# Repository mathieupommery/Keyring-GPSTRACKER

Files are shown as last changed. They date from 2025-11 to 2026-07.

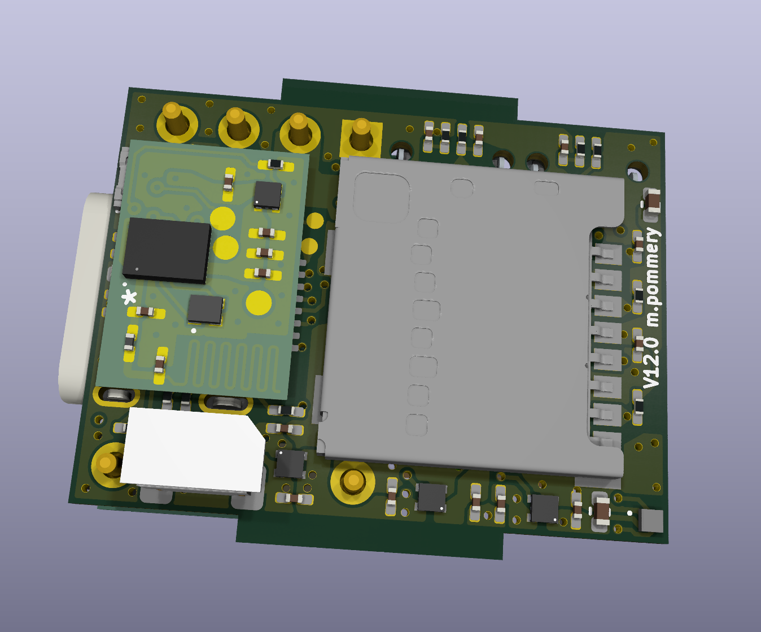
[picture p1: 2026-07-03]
Docs/backv12withda14531.png

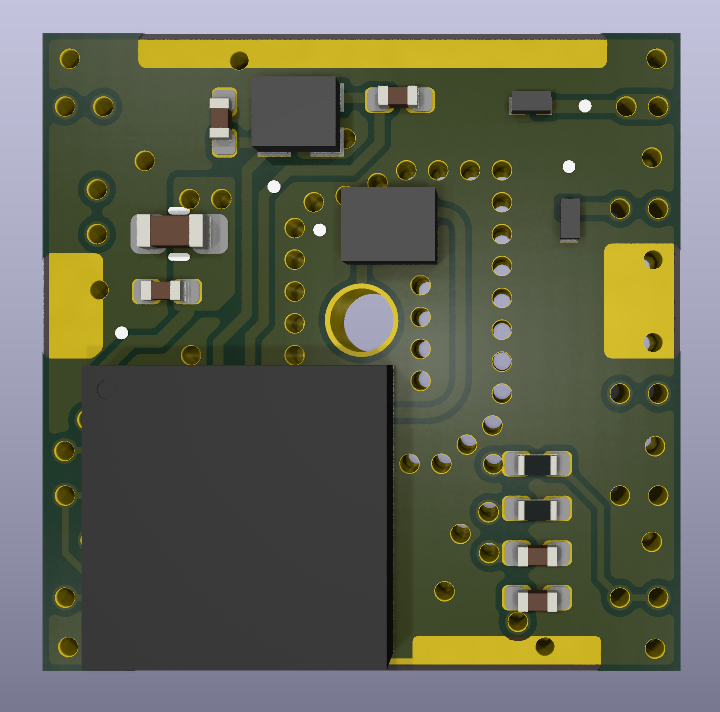
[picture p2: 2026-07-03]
Docs/gpstop.png

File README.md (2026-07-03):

# Keyring-GPSTRACKER (v12.0)

<p align="center">
  <video src="https://github.com/user-attachments/assets/1a3d3f26-0a68-42e8-81eb-b6b98553143f" width="600" controls autoplay loop muted></video>
</p>

An ultra-compact, highly integrated modular GPS logger built around the STM32G0B1KE and a custom u-blox MIA-M10Q implementation. This project is designed as a fully functional, wearable GNSS tracker featuring worldwide offline geographical awareness, high-frequency SD card logging, Bluetooth connectivity, extreme power management (2µA shutdown draw), and modular waterproof enclosures.

## Key Features

* **Configurable High-Speed Logging:** Records tracks directly to the internal MicroSD card in `.GPX` or `.CSV` format. The logging frequency is adjustable, supporting real-time capture from **1Hz up to 10Hz**.
* **Worldwide Offline Awareness & Navigation:** Anywhere in the world, the device can instantly identify the closest city (name, direction, population) or the nearest mountain peak. It provides precise directional pointers by fusing data from the GPS, the MMC5603 compass, and the ICM-42688-P IMU.
* **Topological Barometer Calibration:** Future firmware implementation of an offline map of topological elevation points stored on the SD card, allowing ultra-precise, automatic recalibration of the barometer altitude.
* **BLE Smartphone Connectivity:** An external **DA14531 Bluetooth Low Energy (BLE)** module will handle seamless, low-power synchronization and configuration with a smartphone app.
* **Plug & Play USB:** Acts as a USB Mass Storage Class (MSC) over USB-C. Simply plug the tracker into a computer to access the MicroSD card and retrieve your tracks without removing the card.
* **Extreme Low Power:** Fully active power draw is around ~30mA. In shutdown mode, with only 1 LDO running for the STM32, the system draws just **2µA**.

---

## Modular Hardware Ecosystem (4 Custom PCBs)

The project relies on an ecosystem of four custom PCBs (two 6-layer boards and two 2-layer boards) connected via ultra-compact 5-pin board-to-board connectors.

### 1. Mainboard (6-Layer)
The core of the tracker, engineered to maximize available I/O ports while maintaining a tiny footprint.
* **MCU:** STM32G0B1KE (chosen for native USB FS 2.0, ultra-low power shutdown modes, and only 1 VDD pin).
* **Internal Sensors:** MMC5603 (compass), ICM-42688-P (IMU), and DPS368 (barometer).
* **Storage & Connectivity:** MicroSD card slot operating in SPI mode + external DA14531 BLE module support.
* **Power & Charging:** LTC4065 LiPo battery charger with USB-C connector.

<p align="center">
  v12side
  v12top
</p>

#### BLE Expansion Module (DA14531)
To keep the mainboard ultra-compact while allowing wireless smartphone communication, wireless connectivity is offloaded to a dedicated mini extension PCB. Connected directly to the back of the mainboard via a board-to-board connector, this add-on integrates the ultra-low-power **Renesas DA14531 CodeLess BLE module**.

<p align="center">
  Mainboard Back - Without BLE Module
  backv12withda14531

</p>

### 2. Custom GNSS Receiver Board (6-Layer)
A custom BGA adaptation of the u-blox **MIA-M10Q** receiver with a dedicated SAW filter and a top-mounted ceramic patch antenna. Designed as a footprint clone of the PA1010D, but utilizing a far superior engine capable of 10Hz updates across all constellations simultaneously.

gpstop
gpsbottom

### 3. Display & Waterproof Extension Panel (Breakaway 2-Layer PCB)

To optimize manufacturing, all auxiliary modules are designed as a single **snap-away (breakaway) panelized 2-layer PCB** so they can be produced together in one manufacturing run. Once snapped apart, the panel yields three distinct functional boards:

* **0.42" OLED Carrier Board:** Adapts a 0.42-inch SSD1306 OLED screen to the custom 5/6-pin board-to-board (B2B) connector format. It also breaks out the I2C bus to an external JST SM05B connector and includes an external GPIO breakout for a hardware button.
* **0.49" OLED Carrier Board:** Identical architecture to the 0.42" version (B2B adaptation, JST SM05B I2C breakout, button GPIO), but specifically dimensioned to mount a slightly larger 0.49-inch SSD1306 OLED screen.
* **Waterproof Dive Extension Board:** Designed specifically to mount inside the waterproof enclosure for deep-water excursions. It adds a **TE Connectivity 30-bar external pressure sensor** (effectively turning the tracker into a compact dive computer) and a magnetic **Hall-effect switch** for contactless power/stop-mode toggling through the solid sealed case.

<p align="center">
  auxpcbside2
  auxpcbside1
</p>

## Smart Power Architecture

Power is cleanly isolated and distributed via 3 independent ultra-low IQ LDOs, controlled by the MCU:
* **LDO 1 (Always-on / MCU baseline):** Powers the STM32 directly. Responsible for the 2µA deep shutdown consumption.
* **LDO 2 (Switched):** Dedicated exclusively to the GNSS module.
* **LDO 3 (Switched):** Powers the SSD1306 display, the MicroSD card, external sensors (including the BLE module), and internal sensors.

---

## Enclosure System: Standard vs. Waterproof (Dive Mode)

The tracker features a modular, tool-free swap enclosure system depending on your activity:

### 1. Standard Compact Case
The daily-use enclosure. It is ultra-compact, non-waterproof, and provides direct access to the OLED display, physical buttons, MicroSD card slot, and USB-C port for charging and mass-storage data transfer.

balise

### 2. Waterproof Dive Case
Similar to a GoPro housing, this heavy-duty case is designed for underwater excursions down to several hundred meters. 
* **How it works:** You remove the mainboard from the standard case, connect it to the **Waterproof Extension Board** (with the 30-bar sensor and Hall switch already mounted inside the dive case), turn it on, and seal the enclosure.
* **Note:** While in this temporary dive case, USB charging and physical MicroSD card access are blocked to ensure 100% water tightness. Power state is managed entirely through the external magnetic Hall sensor.

watercase1

---

## Open Source

This project is fully open source! Feel free to explore the schematics, layouts, and firmware. If you find this project interesting or build your own, **please consider leaving a ⭐ on the repository!**

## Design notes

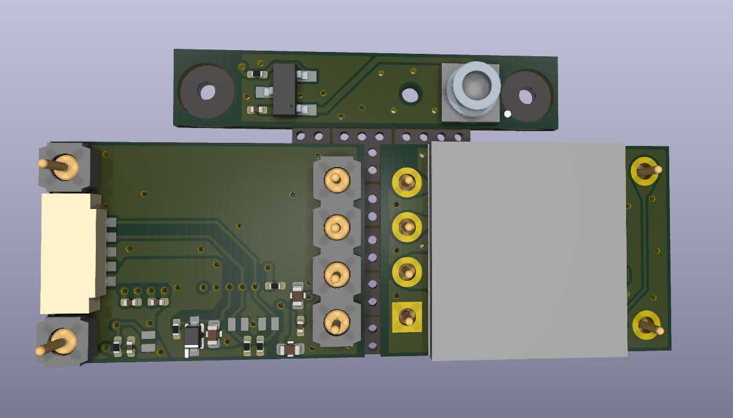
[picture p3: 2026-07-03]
Docs/auxpcbside1.png

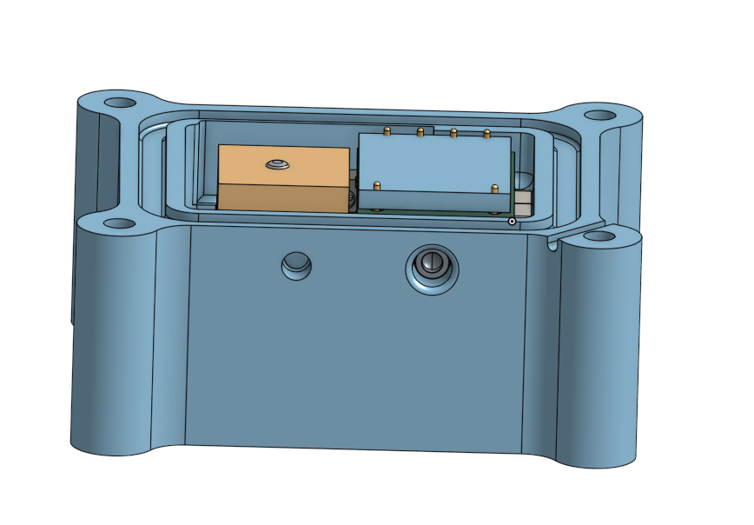
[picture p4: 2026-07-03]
Docs/watercase2.png

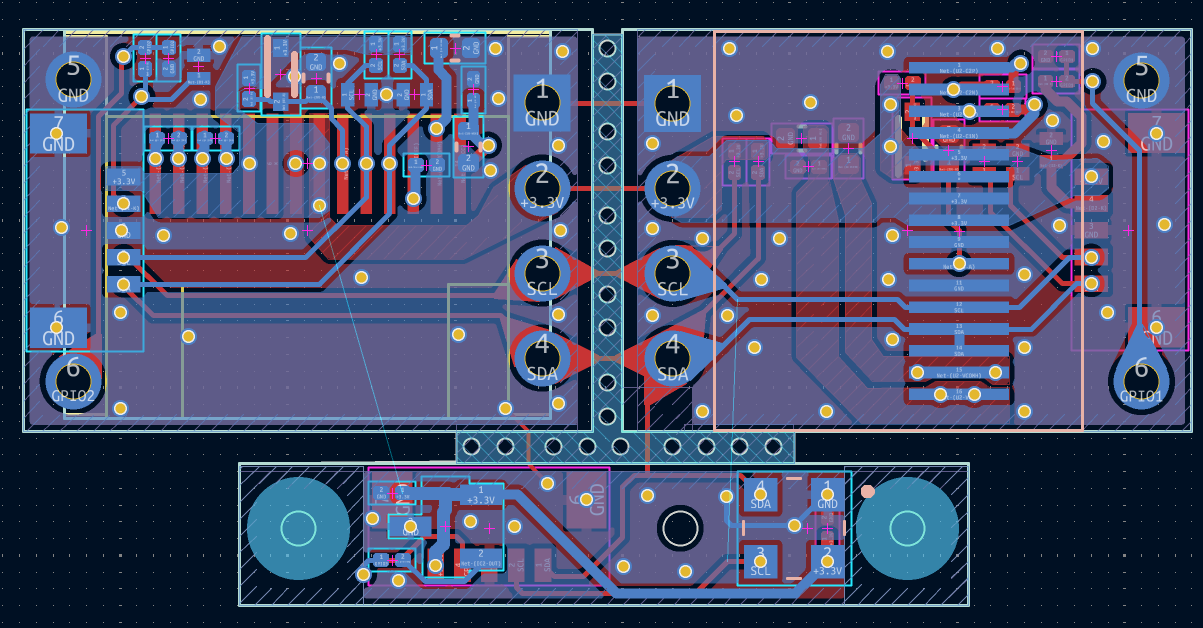
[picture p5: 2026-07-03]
Docs/auxpcb.png

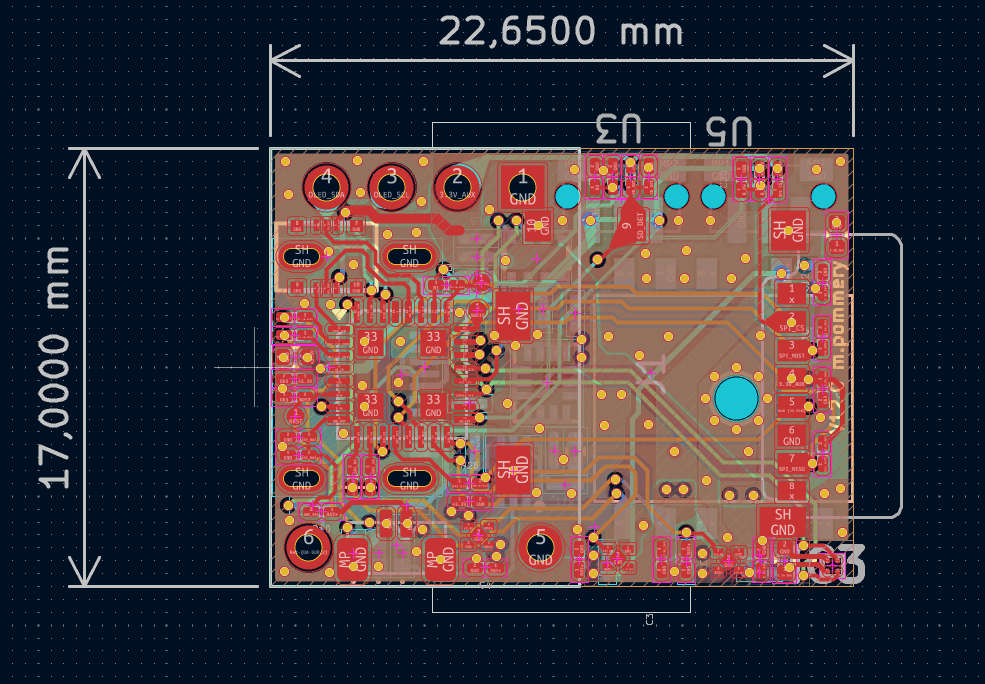
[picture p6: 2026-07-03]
Docs/v12pcb.png

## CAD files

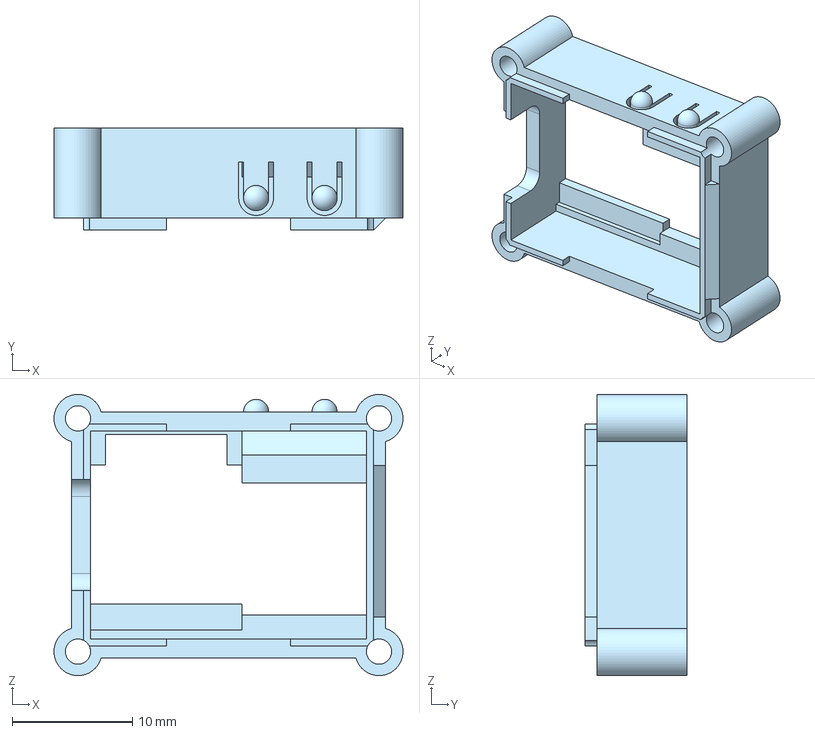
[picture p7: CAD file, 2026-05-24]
Hardware/3d schématic/case/top_case_v9.step
29.1 x 8.54 x 23.4 mm

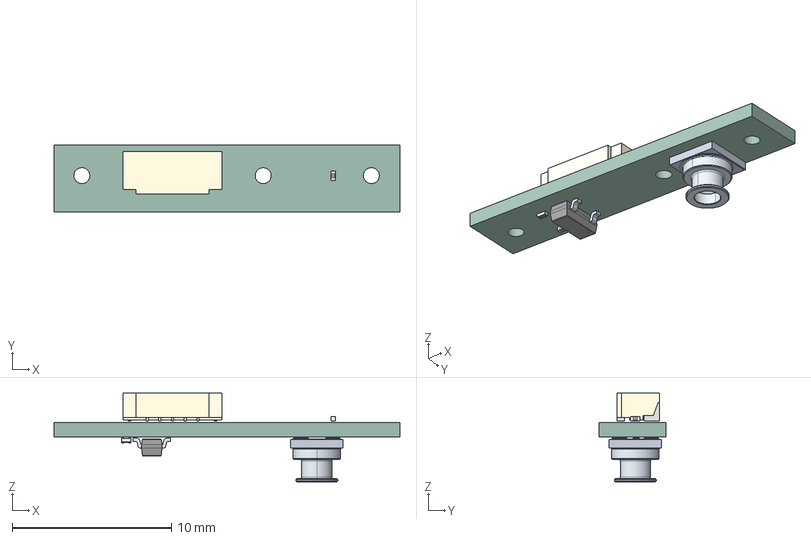
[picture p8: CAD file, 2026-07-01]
Hardware/all_pcb_screen_gps/step/barometer.step
21.8 x 4.24 x 5.57 mm
C_0201_0603Metric x 2
SM05B-SURS-TF_LF__SN_
PinsArrayL
FilletPinR
R_0201_0603Metric
MS583730BA01-50
custom_screen_PCB

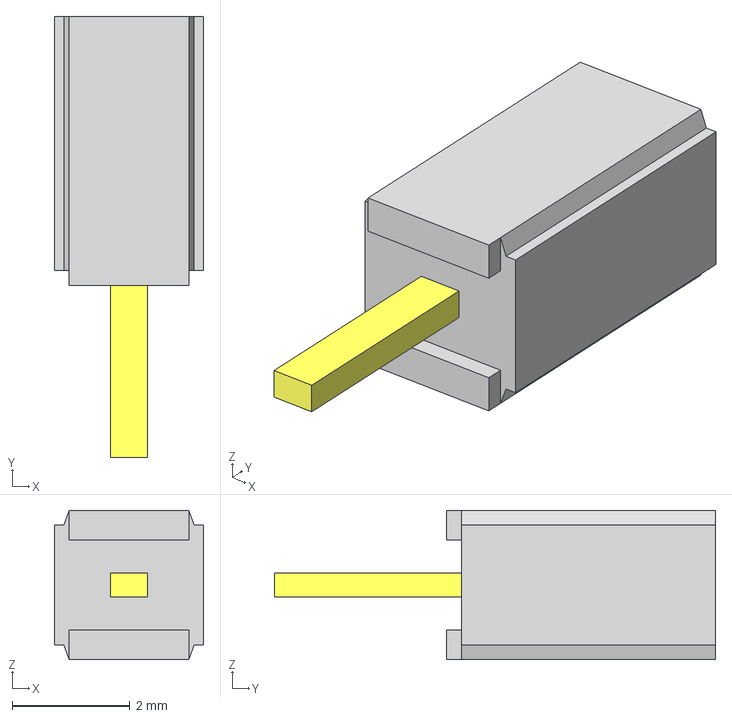
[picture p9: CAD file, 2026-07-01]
Hardware/hardware v11/lib_local/SLW-101-01-G-S.stp
2.54 x 7.49 x 2.54 mm
SLW-101-01-S_socket
C-28-01-01-S

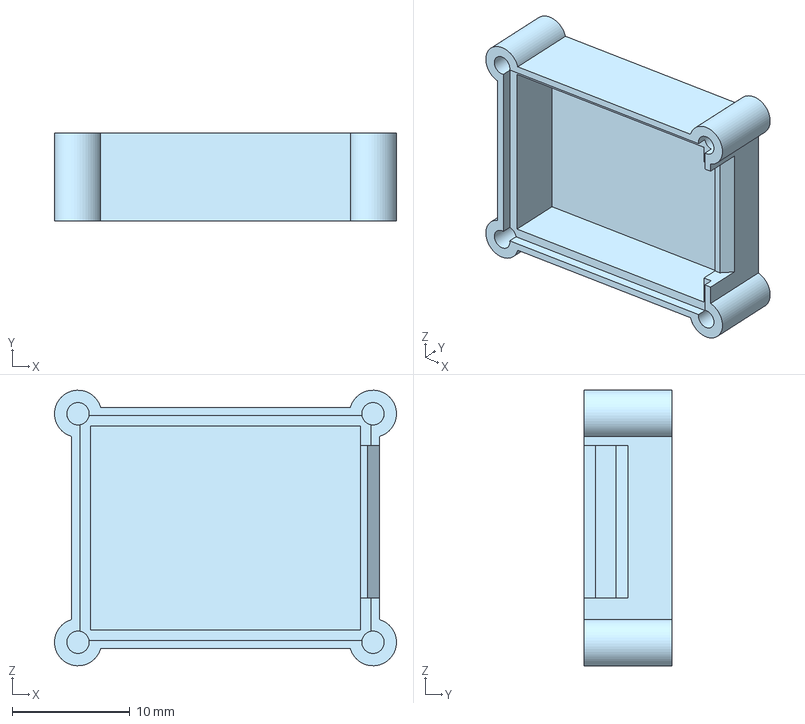
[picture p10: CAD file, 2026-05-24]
Hardware/3d schématic/case/bottom_case_v9.step
29.1 x 7.50 x 23.4 mm

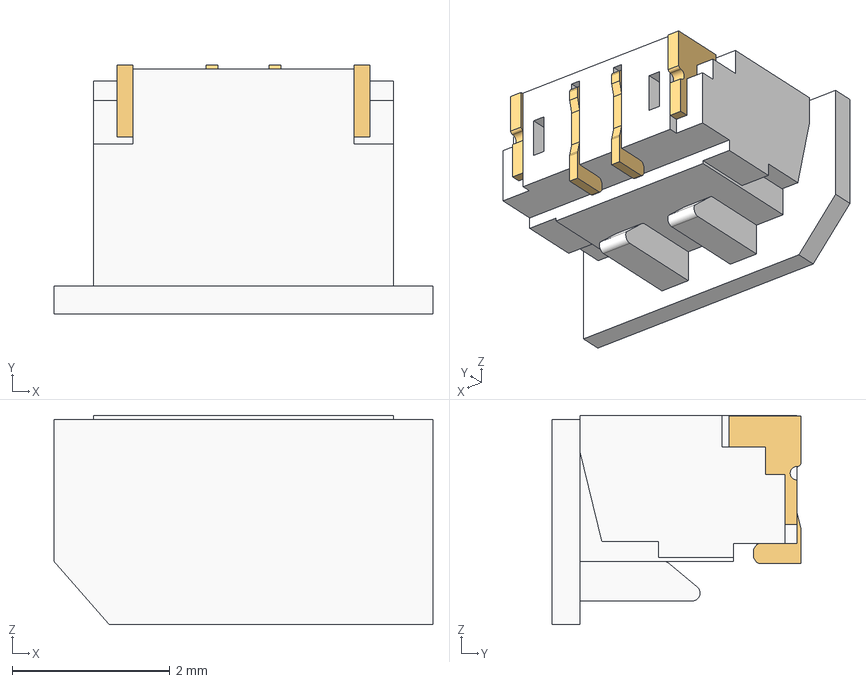
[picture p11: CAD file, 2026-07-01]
Hardware/3d schématic/composant/bm02b-sur.stp
4.80 x 3.15 x 2.65 mm
6893xx124022_Pin 2 x 2
6893xx124022_Pin x 2
6893xx124022_Cap

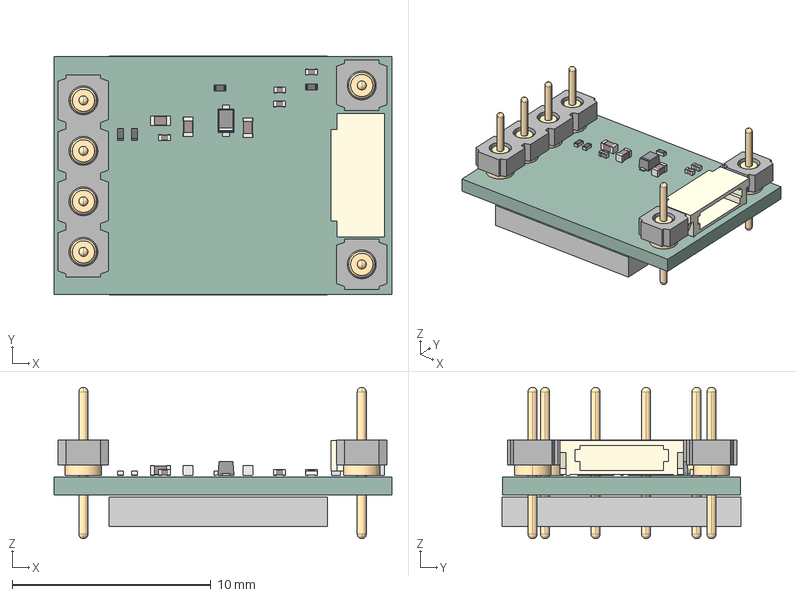
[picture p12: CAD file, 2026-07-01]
Hardware/all_pcb_screen_gps/step/042inch.step
17.0 x 12.0 x 7.62 mm
C_0402_1005Metric x 3
R_0201_0603Metric x 4
C_0201_0603Metric x 4
PinKIdent
PinK
PinA
SM05B-SURS-TF_LF__SN_
0.42inch
P3XX-11-012-00-000000_P301-11-012-00-000000 x 2
P3XX-11-012-00-000000_P304-11-012-00-000000
custom_screen_PCB

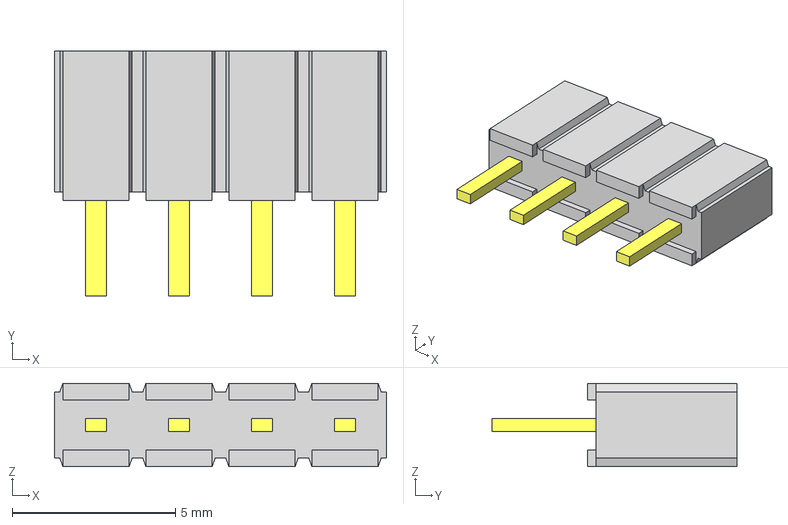
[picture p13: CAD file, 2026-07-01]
Hardware/hardware v11/lib_local/SLW-104-01-G-S.stp
10.2 x 7.49 x 2.54 mm
SLW-104-01-S_socket
C-28-01-04-S

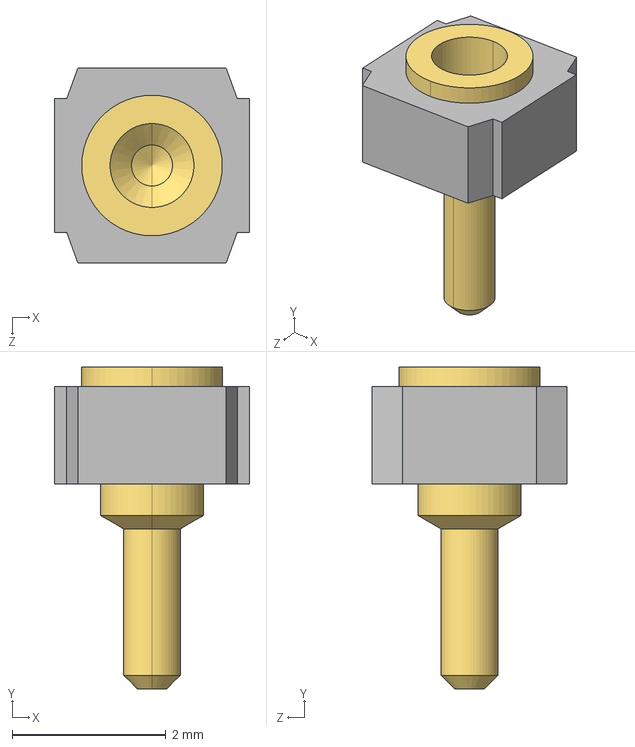
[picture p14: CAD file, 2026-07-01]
Hardware/3d schématic/composant/mill-max-315-13-101-41-004000.STEP
2.54 x 4.19 x 2.54 mm
P3XX-11-012-00-000000_P301-11-012-00-000000

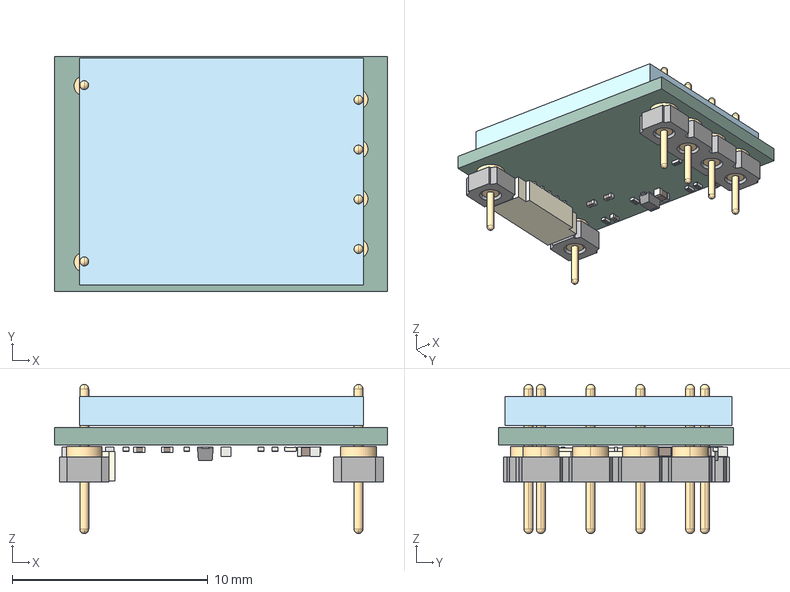
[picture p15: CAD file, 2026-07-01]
Hardware/all_pcb_screen_gps/step/049inch.step
17.0 x 12.0 x 7.62 mm
0.49inch
P3XX-11-012-00-000000_P301-11-012-00-000000 x 2
P3XX-11-012-00-000000_P304-11-012-00-000000
C_0402_1005Metric x 3
R_0201_0603Metric x 5
C_0201_0603Metric x 4
PinKIdent
PinK
PinA
SM05B-SURS-TF_LF__SN_
custom_screen_PCB

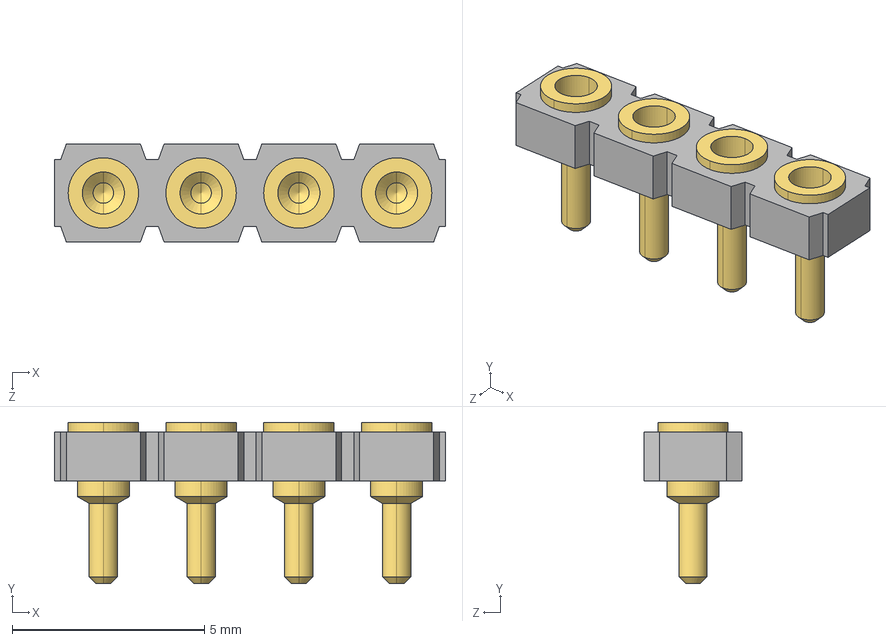
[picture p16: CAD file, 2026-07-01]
Hardware/3d schématic/composant/mill-max-315-13-104-41-004000.STEP
10.2 x 4.19 x 2.54 mm
P3XX-11-012-00-000000_P304-11-012-00-000000

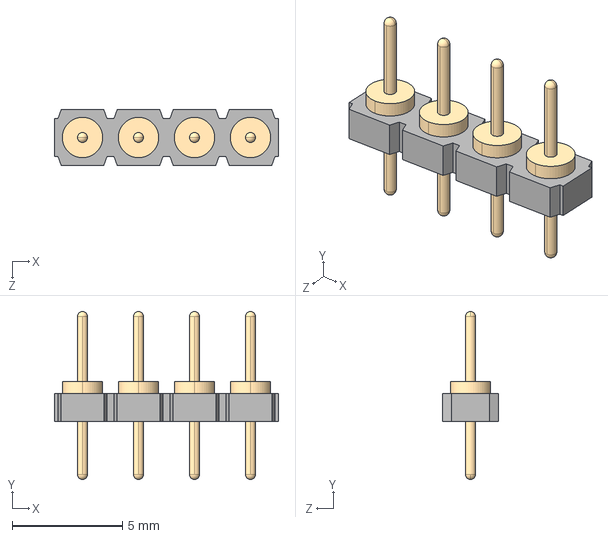
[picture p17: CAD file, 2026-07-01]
Hardware/3d schématic/composant/mill-max-335-10-104-00-160000.STEP
10.2 x 7.62 x 2.54 mm
P3XX-11-012-00-000000_P304-11-012-00-000000

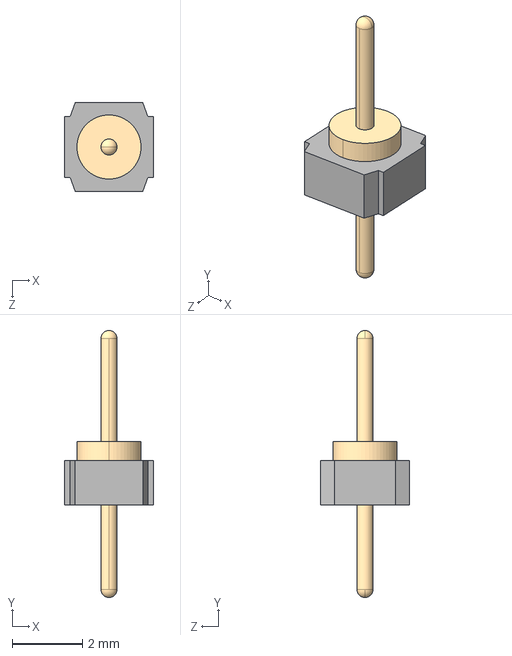
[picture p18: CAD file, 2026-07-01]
Hardware/3d schématic/composant/mill-max-335-10-101-00-160000.STEP
2.54 x 7.62 x 2.54 mm
P3XX-11-012-00-000000_P301-11-012-00-000000

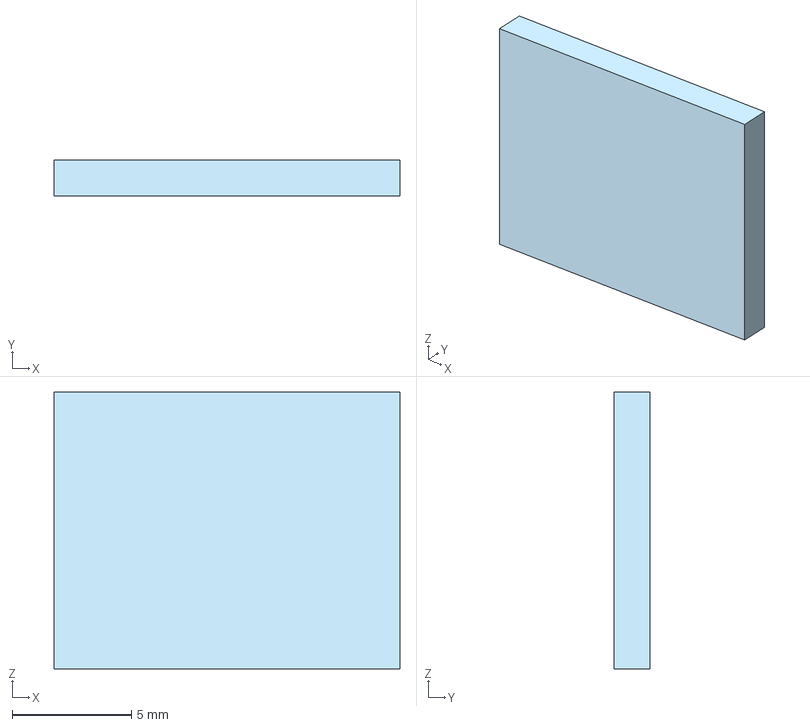
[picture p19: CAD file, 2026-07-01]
Hardware/3d schématic/composant/0.49inch.step
14.5 x 1.50 x 11.6 mm

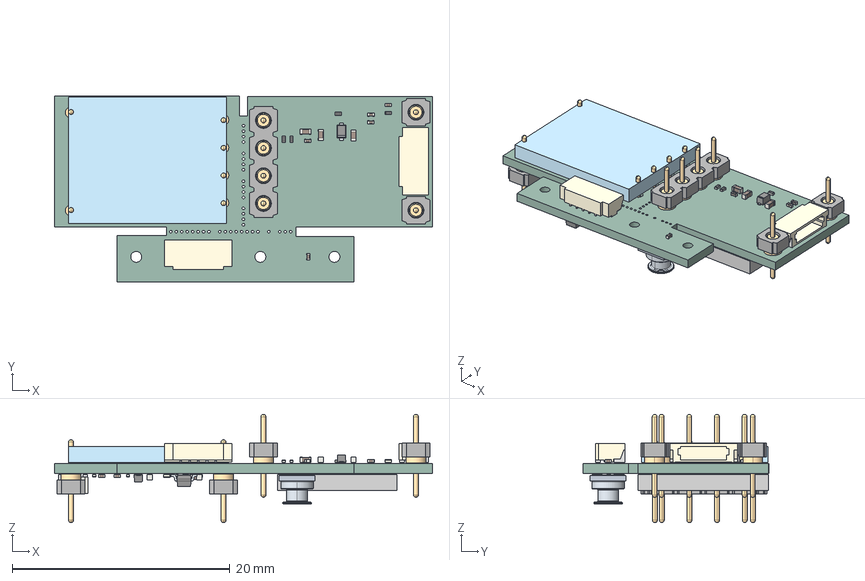
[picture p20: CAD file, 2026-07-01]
Hardware/3d schématic/composant/ssd1306.step
34.7 x 17.1 x 9.94 mm
C_0402_1005Metric x 6
R_0201_0603Metric x 10
C_0201_0603Metric x 10
PinKIdent x 2
PinK x 2
PinA x 2
SM05B-SURS-TF_LF__SN_ x 3
0.49inch
P3XX-11-012-00-000000_P301-11-012-00-000000 x 4
P3XX-11-012-00-000000_P304-11-012-00-000000 x 2
PinsArrayL
FilletPinR
0.42inch
MS583730BA01-50
custom_screen_PCB

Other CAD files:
Hardware/3d schématic/composant/BM06B-SURS-TF-LF--SN---3DModel-STEP-56544.STEP
Hardware/3d schématic/composant/0.42inch.step
Hardware/3d schématic/composant/CD-PA1010D--3DModel-STEP-271329.STEP
Hardware/3d schématic/composant/KXT321LHS.stp
Hardware/3d schématic/composant/104031-0811.stp
Hardware/3d schématic/composant/DA14531.step
Hardware/3d schématic/composant/LDLN025PU50R.stp
Hardware/3d schématic/composant/LTC4065AEDCPBF.stp
Hardware/3d schématic/pcb/DA14531pcb.step

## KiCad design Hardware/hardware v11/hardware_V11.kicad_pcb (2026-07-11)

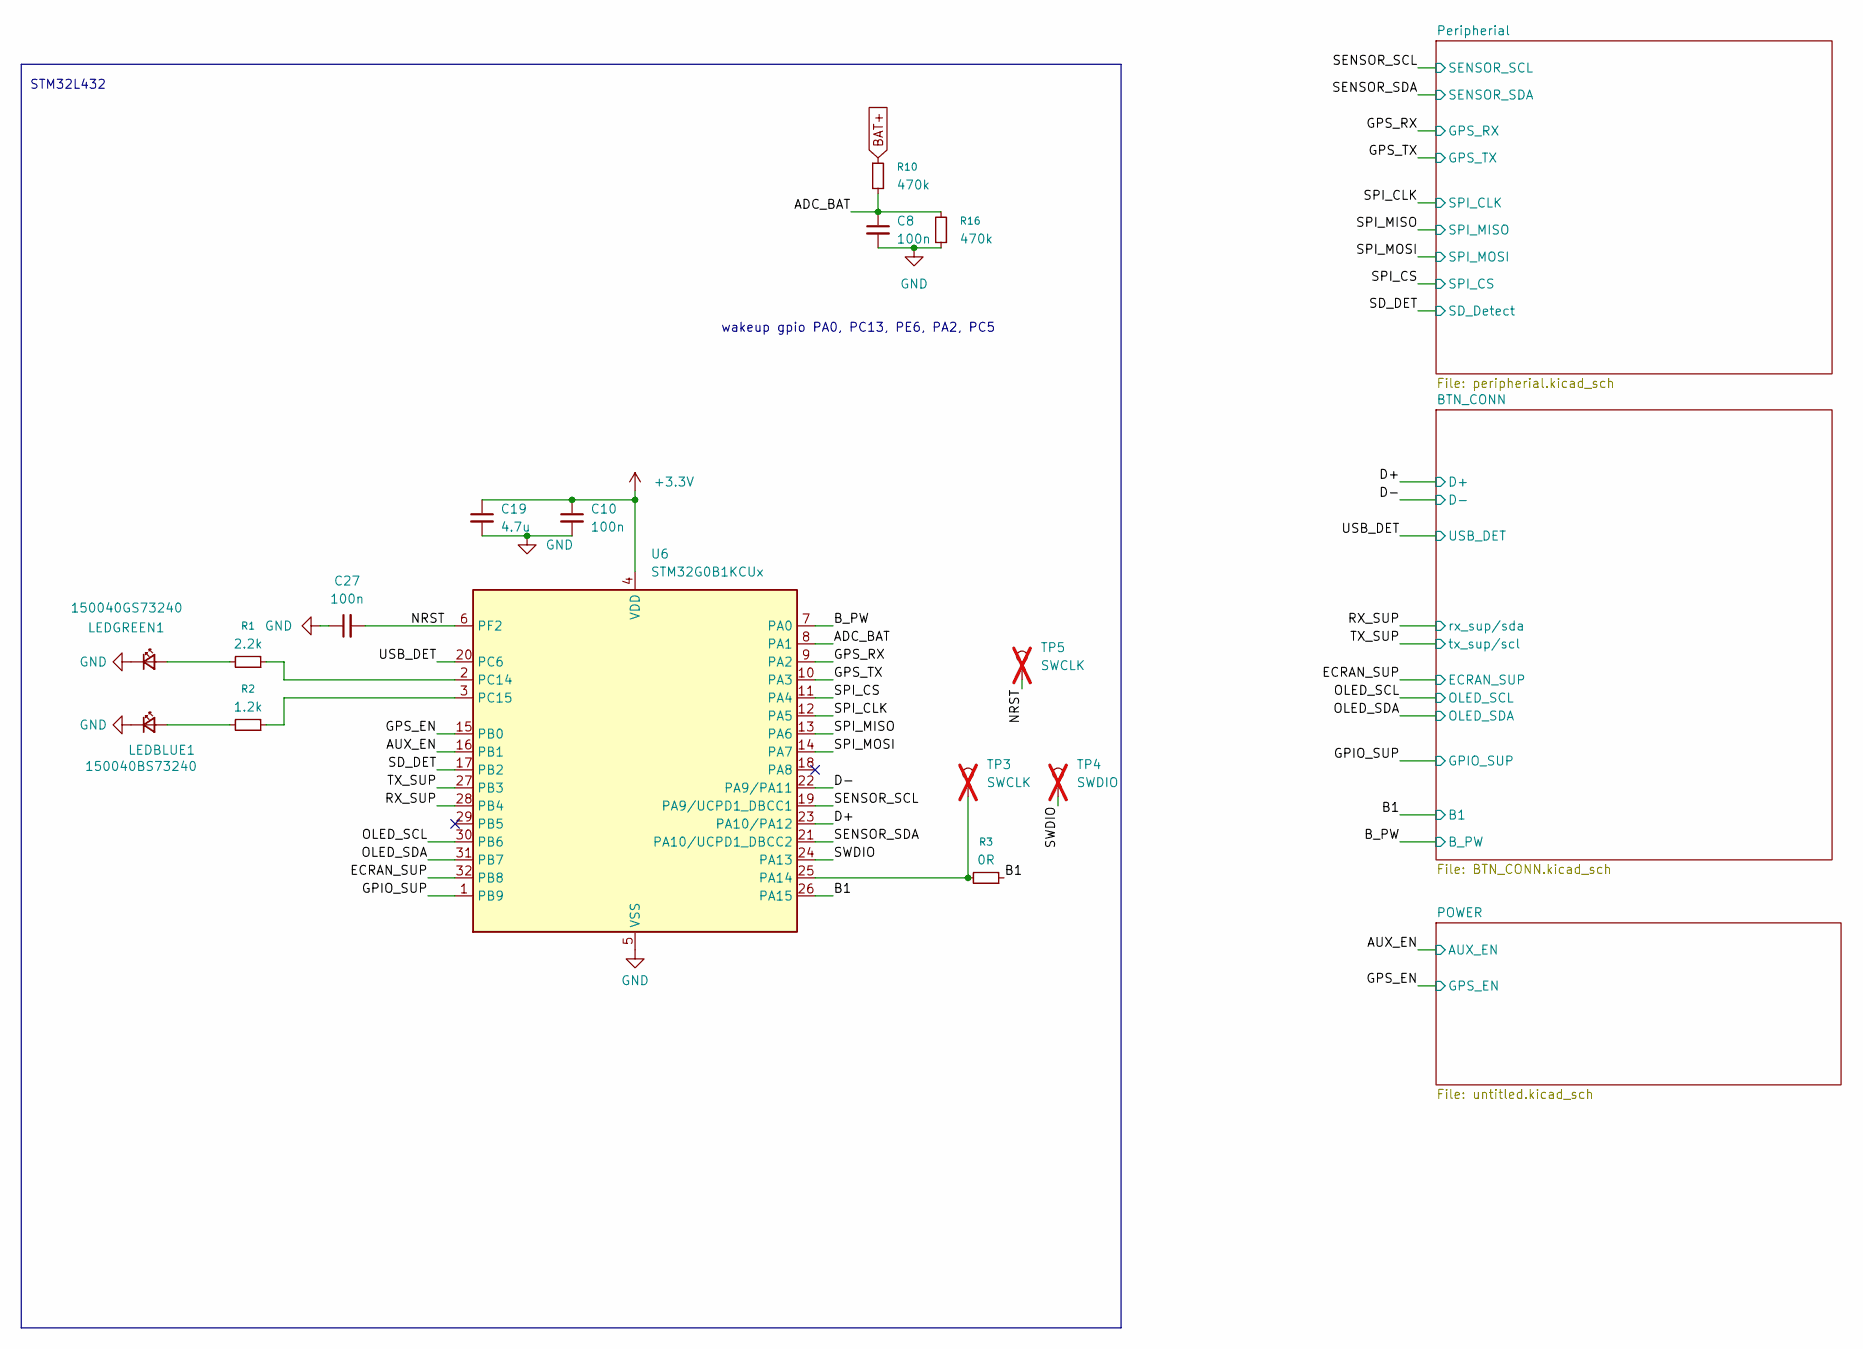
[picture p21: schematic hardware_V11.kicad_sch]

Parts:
C8, C10, C27: 100n; C_0201_0603Metric_Pad0.64x0.40mm_HandSolder
C19: 4.7u; C_0402_1005Metric
LEDBLUE1: 150040BS73240; LED_0402_1005Metric; Manufacturer_Part_Number 150040BS73240; Mouser Part Number 710-150040BS73240
LEDGREEN1: 150040GS73240; LED_0402_1005Metric; Manufacturer_Part_Number 150040GS73240; Mouser Part Number 710-150040GS73240
R1: 2.2k; R_0201_0603Metric_Pad0.64x0.40mm_HandSolder; Mouser Part Number 603-RC0201JR-07510RL
R2: 1.2k; R_0201_0603Metric_Pad0.64x0.40mm_HandSolder; Mouser Part Number 603-RC0201JR-07510RL
R3: 0R; R_0201_0603Metric_Pad0.64x0.40mm_HandSolder; Mouser Part Number 603-RC0201JR-07510RL
R10, R16: 470k; R_0201_0603Metric_Pad0.64x0.40mm_HandSolder; Mouser Part Number 603-AC0201FR-07470KL
TP3, TP5: SWCLK; pad_0.7mm; not fitted
TP4: SWDIO; pad_0.7mm; not fitted
U6: STM32G0B1KCUx; QFN-32-1EP_5x5mm_P0.5mm_EP3.45x3.45mm

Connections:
+3.3V: C10.1, C19.1, U6.4 (VDD); also elsewhere on the board
/ADC_BAT: C8.1, R10.2, R16.2, U6.8 (PA1)
/AUX_EN: U6.16 (PB1); also elsewhere on the board
/B1: R3.1, U6.26 (PA15); also elsewhere on the board
/B_PW: U6.7 (PA0); also elsewhere on the board
/D+: U6.23 (PA10/PA12); also elsewhere on the board
/D-: U6.22 (PA9/PA11); also elsewhere on the board
/ECRAN_SUP: U6.32 (PB8); also elsewhere on the board
/GPIO_SUP: U6.1 (PB9); also elsewhere on the board
/GPS_EN: U6.15 (PB0); also elsewhere on the board
/GPS_RX: U6.9 (PA2); also elsewhere on the board
/GPS_TX: U6.10 (PA3); also elsewhere on the board
/NRST: C27.2, TP5.1 (1_1), U6.6 (PF2)
/OLED_SCL: U6.30 (PB6); also elsewhere on the board
/OLED_SDA: U6.31 (PB7); also elsewhere on the board
/RX_SUP: U6.28 (PB4); also elsewhere on the board
/SD_DET: U6.17 (PB2); also elsewhere on the board
/SENSOR_SCL: U6.19 (PA9/UCPD1_DBCC1); also elsewhere on the board
/SENSOR_SDA: U6.21 (PA10/UCPD1_DBCC2); also elsewhere on the board
/SPI_CLK: U6.12 (PA5); also elsewhere on the board
/SPI_CS: U6.11 (PA4); also elsewhere on the board
/SPI_MISO: U6.13 (PA6); also elsewhere on the board
/SPI_MOSI: U6.14 (PA7); also elsewhere on the board
/SWDIO: TP4.1 (1_1), U6.24 (PA13)
/TX_SUP: U6.27 (PB3); also elsewhere on the board
/USB_DET: U6.20 (PC6); also elsewhere on the board
BAT+: R10.1; also elsewhere on the board
GND: C8.2, C10.2, C19.2, C27.1, LEDBLUE1.1 (K), LEDGREEN1.1 (K), R16.1, U6.5 (VSS), U6.33 (VSS); also elsewhere on the board
unnamed: LEDBLUE1.2 (A), R2.2
unnamed: LEDGREEN1.2 (A), R1.2
unnamed: R3.2, TP3.1 (1_1), U6.25 (PA14)
unnamed: R1.1, U6.2 (PC14)
unnamed: R2.1, U6.3 (PC15)

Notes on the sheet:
STM32L432
wakeup gpio PA0, PC13, PE6, PA2, PC5

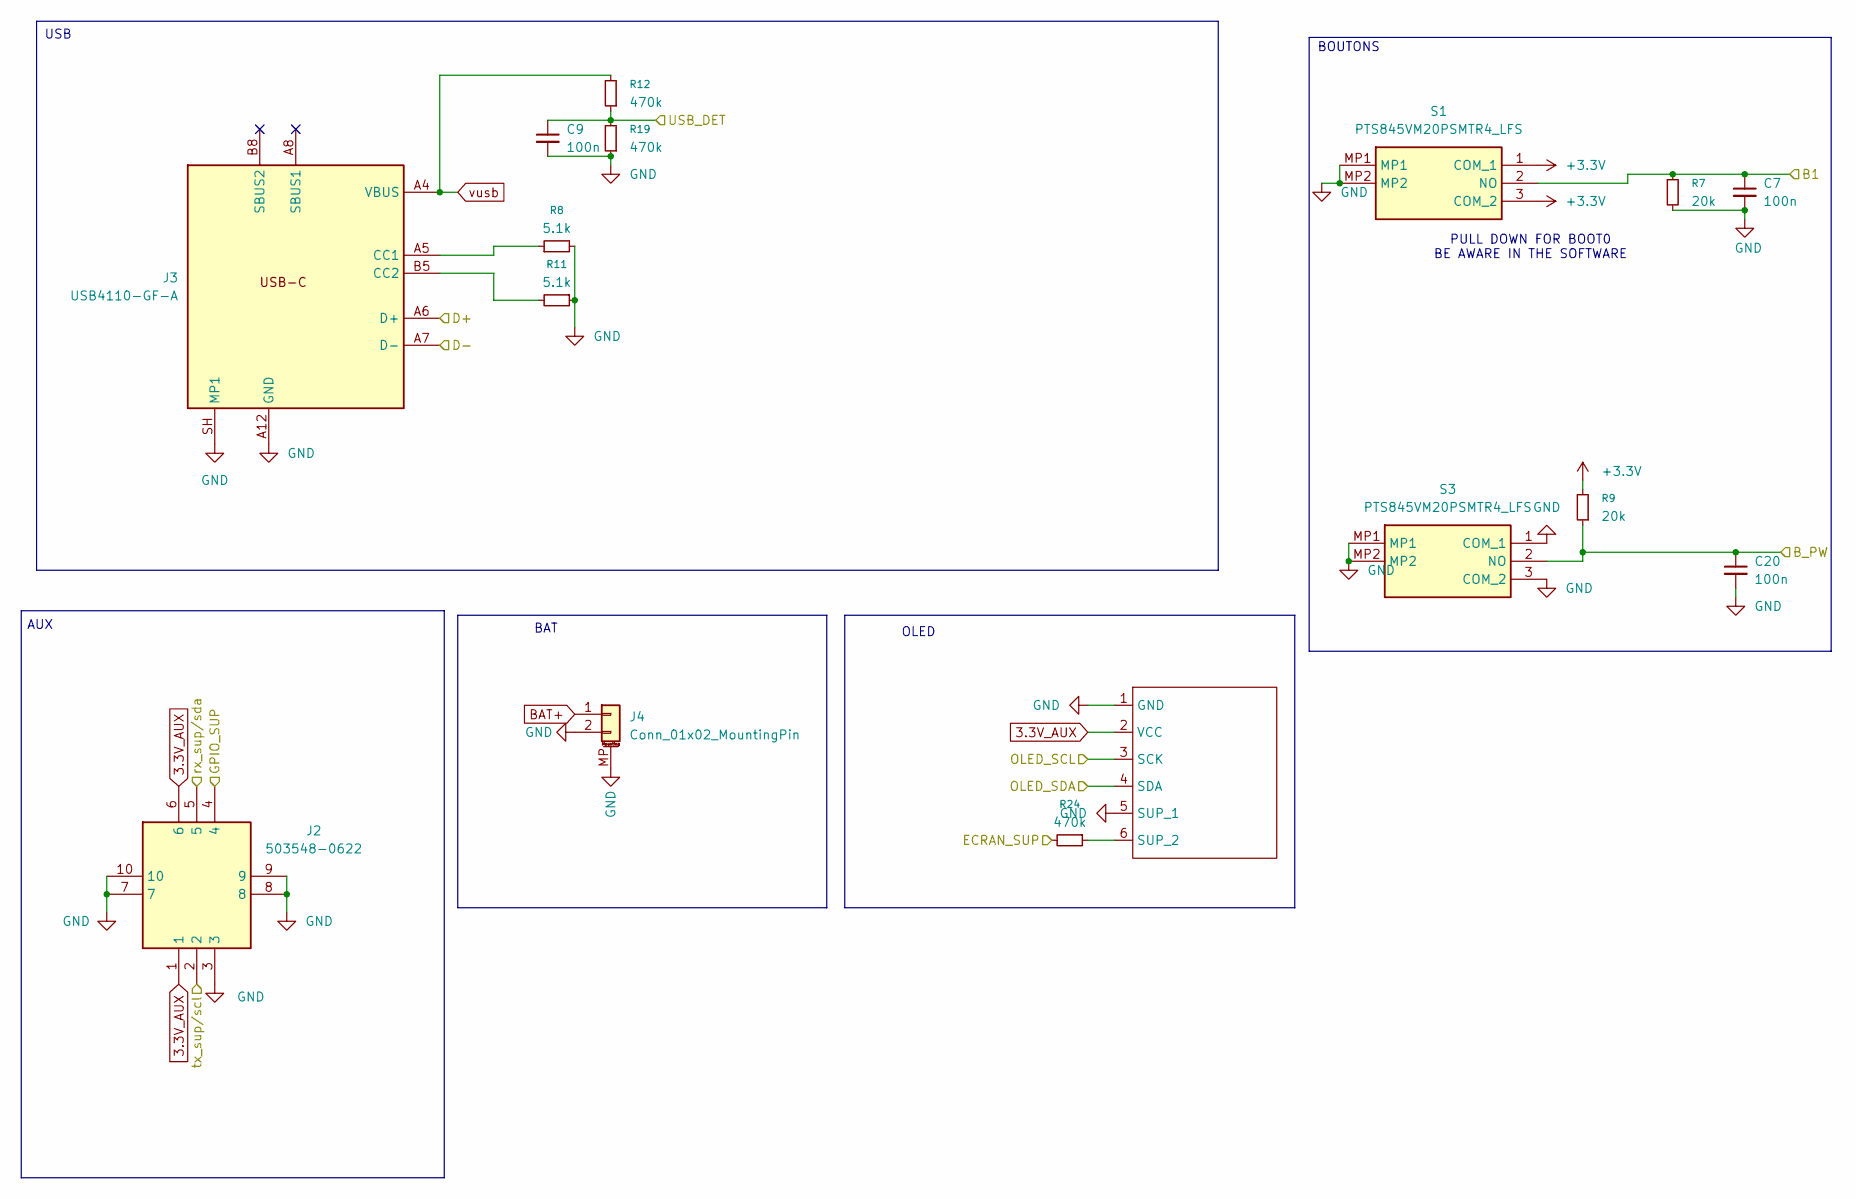
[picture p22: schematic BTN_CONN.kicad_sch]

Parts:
C7, C9, C20: 100n; C_0201_0603Metric_Pad0.64x0.40mm_HandSolder
J2: 503548-0622; 5035480622; Manufacturer_Part_Number 503548-0622; Mouser Part Number 538-503548-0622
J3: USB4110-GF-A; USB_C_Receptacle_GCT_USB4105-xx-A_16P_TopMnt_Horizontal; Mouser Part Number 640-USB4110-GF-A
J4: Conn_01x02_MountingPin; JST_SUR_BM02B-SURS-TF_1x02-1MP_P0.80mm_Vertical
R7, R9: 20k; R_0201_0603Metric_Pad0.64x0.40mm_HandSolder; Mouser Part Number 603-AC0201FR-0720KL
R8, R11: 5.1k; R_0201_0603Metric_Pad0.64x0.40mm_HandSolder; Mouser Part Number 603-AC0201FR-0720KL
R12, R19, R24: 470k; R_0201_0603Metric_Pad0.64x0.40mm_HandSolder; Mouser Part Number 603-AC0201FR-0720KL
S1, S3: PTS845VM20PSMTR4_LFS; PTS845VM20PSMTR4LFS; Manufacturer_Part_Number PTS845VM20PSMTR4 LFS; Mouser Part Number 611-PTS845VM20PSMTR4
U4: ssd1306_5point

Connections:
3.3V_AUX: J2.1, J2.6, U4.2 (VCC); also elsewhere on the board
+3.3V: R9.2, S1.1 (COM_1), S1.3 (COM_2); also elsewhere on the board
/B1: C7.1, R7.1, S1.2 (NO); also elsewhere on the board
/B_PW: C20.1, R9.1, S3.2 (NO); also elsewhere on the board
/D+: J3.A6 (D+), J3.B6 (D+); also elsewhere on the board
/D-: J3.A7 (D-), J3.B7 (D-); also elsewhere on the board
/ECRAN_SUP: R24.2; also elsewhere on the board
/GPIO_SUP: J2.4; also elsewhere on the board
/OLED_SCL: U4.3 (SCK); also elsewhere on the board
/OLED_SDA: U4.4 (SDA); also elsewhere on the board
/RX_SUP: J2.5; also elsewhere on the board
/TX_SUP: J2.2; also elsewhere on the board
/USB_DET: C9.1, R12.1, R19.2; also elsewhere on the board
BAT+: J4.1; also elsewhere on the board
GND: C7.2, C9.2, C20.2, J2.3, J2.7, J2.8, J2.9, J2.10, J3.A1 (GND), J3.A12 (GND), J3.B1 (GND), J3.B12 (GND), J3.SH (MP1), J4.2, J4.MP (MountPin), R7.2, R8.2, R11.1, R19.1, S1.MP1, S1.MP2, S3.1 (COM_1), S3.3 (COM_2), S3.MP1, S3.MP2, U4.1 (GND), U4.5 (SUP_1); also elsewhere on the board
unnamed: J3.A5 (CC1), R8.1
unnamed: J3.B5 (CC2), R11.2
unnamed: R24.1, U4.6 (SUP_2)
vusb: J3.A4 (VBUS), J3.A9 (VBUS), J3.B4 (VBUS), J3.B9 (VBUS), R12.2; also elsewhere on the board

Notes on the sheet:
AUX
BOUTONS
USB
PULL DOWN FOR BOOT0 BE AWARE IN THE SOFTWARE
OLED
BAT

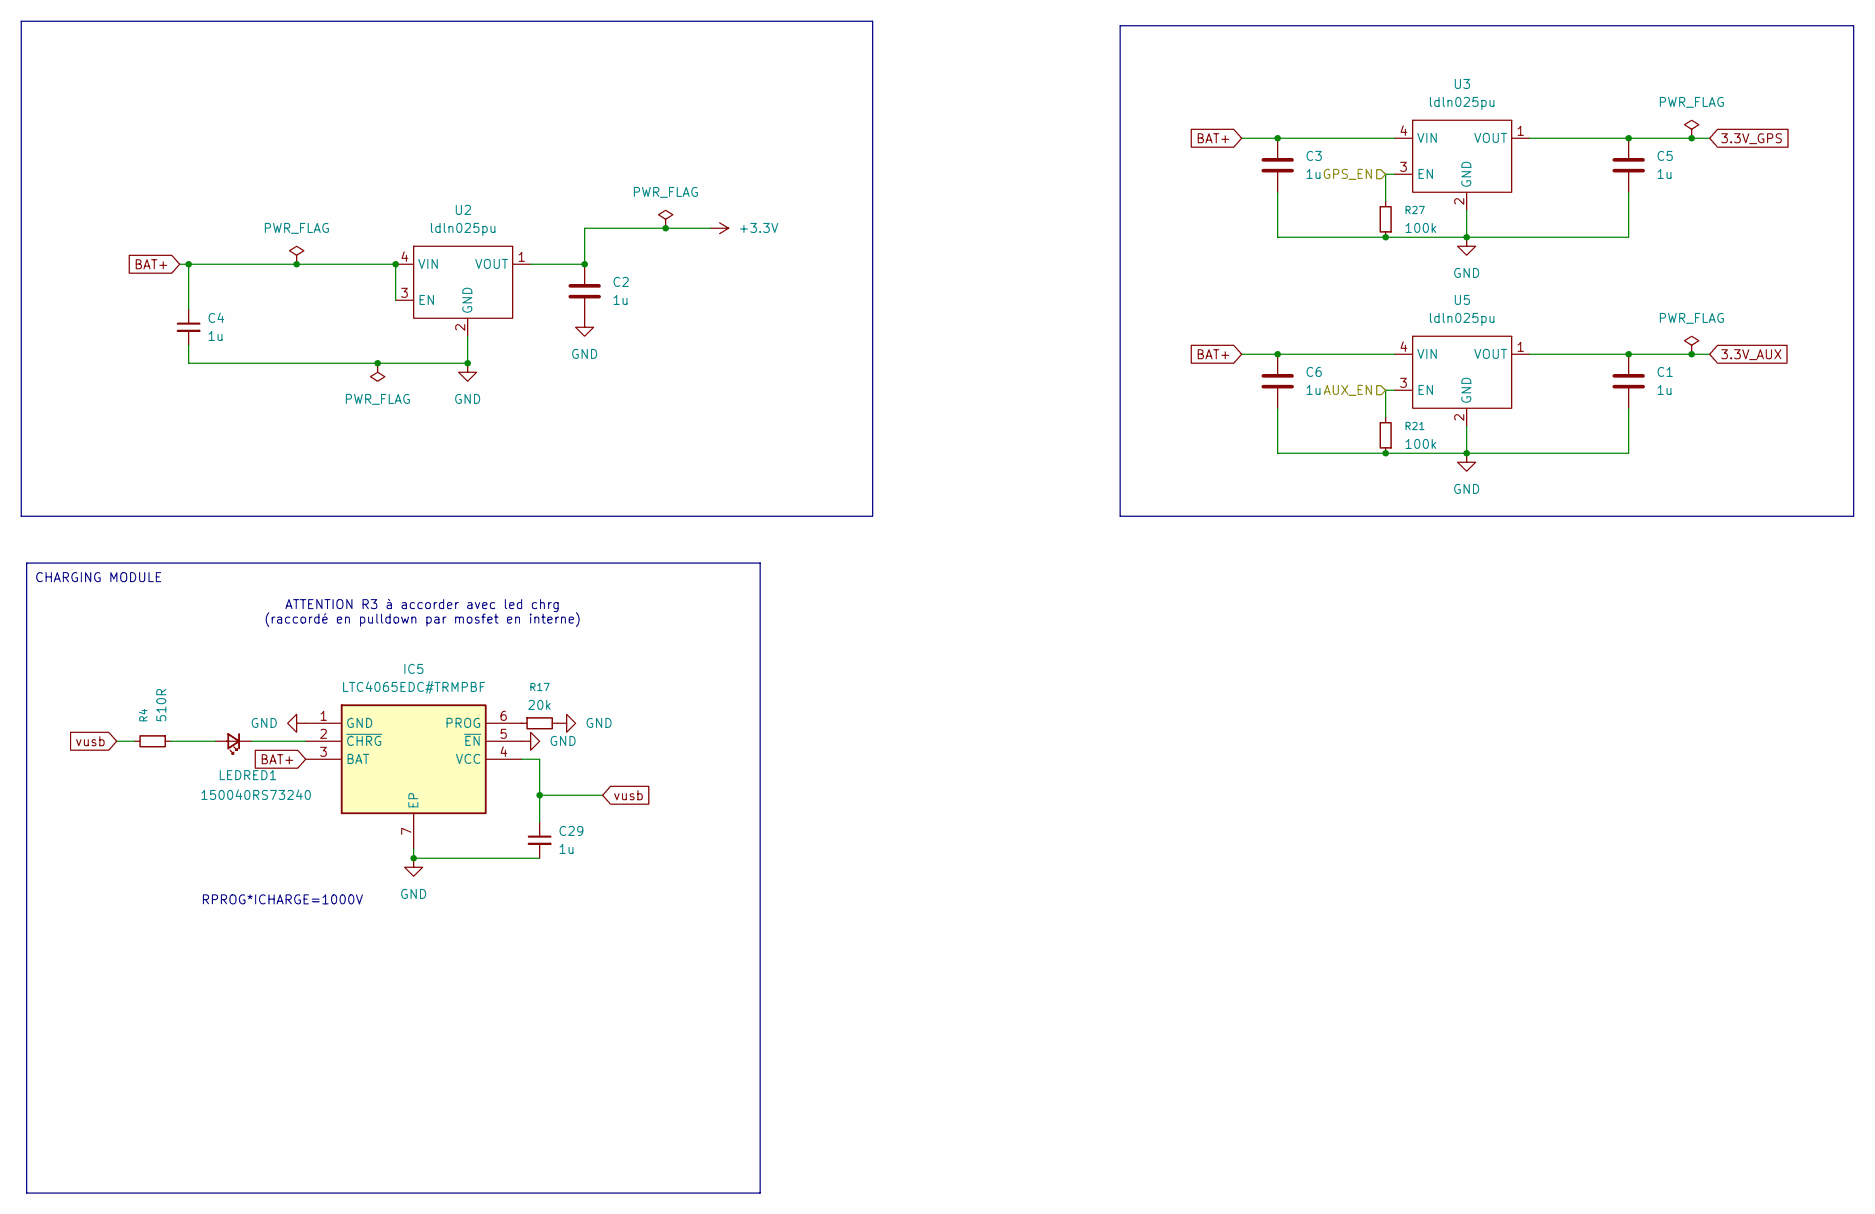
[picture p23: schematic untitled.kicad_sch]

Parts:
C1, C2, C3, C4, C5, C6, C29: 1u; C_0201_0603Metric_Pad0.64x0.40mm_HandSolder
IC5: LTC4065EDC#TRMPBF; SON50P200X200X80-7N-D; Manufacturer_Part_Number LTC4065EDC#TRMPBF; Mouser Part Number 584-LTC4065EDCTRMPBF
LEDRED1: 150040RS73240; LED_0402_1005Metric; Manufacturer_Part_Number 150040GS73240; Mouser Part Number 710-150040GS73240
R4: 510R; R_0201_0603Metric_Pad0.64x0.40mm_HandSolder; Mouser Part Number 603-RC0201JR-07510RL
R17: 20k; R_0201_0603Metric_Pad0.64x0.40mm_HandSolder; Mouser Part Number 603-AC0201FR-0720KL
R21, R27: 100k; R_0201_0603Metric_Pad0.64x0.40mm_HandSolder; Mouser Part Number 603-RC0201BR-07100KL
U2, U3, U5: ldln025pu; Mouser Part Number 511-LDLN025PU33R

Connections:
3.3V_AUX: C1.1, U5.1 (VOUT); also elsewhere on the board
3.3V_GPS: C5.1, U3.1 (VOUT); also elsewhere on the board
+3.3V: C2.1, U2.1 (VOUT); also elsewhere on the board
/AUX_EN: R21.2, U5.3 (EN); also elsewhere on the board
/GPS_EN: R27.2, U3.3 (EN); also elsewhere on the board
BAT+: C3.1, C4.1, C6.1, IC5.3 (BAT), U2.3 (EN), U2.4 (VIN), U3.4 (VIN), U5.4 (VIN); also elsewhere on the board
GND: C1.2, C2.2, C3.2, C4.2, C5.2, C6.2, C29.2, IC5.1 (GND), IC5.5 (~EN), IC5.7 (EP), R17.2, R21.1, R27.1, U2.2 (GND), U3.2 (GND), U5.2 (GND); also elsewhere on the board
unnamed: IC5.6 (PROG), R17.1
unnamed: IC5.2 (~CHRG), LEDRED1.1 (K)
unnamed: LEDRED1.2 (A), R4.1
vusb: C29.1, IC5.4 (VCC), R4.2; also elsewhere on the board

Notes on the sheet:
RPROG*ICHARGE=1000V
ATTENTION R3 à accorder avec led chrg (raccordé en pulldown par mosfet en interne)
CHARGING MODULE

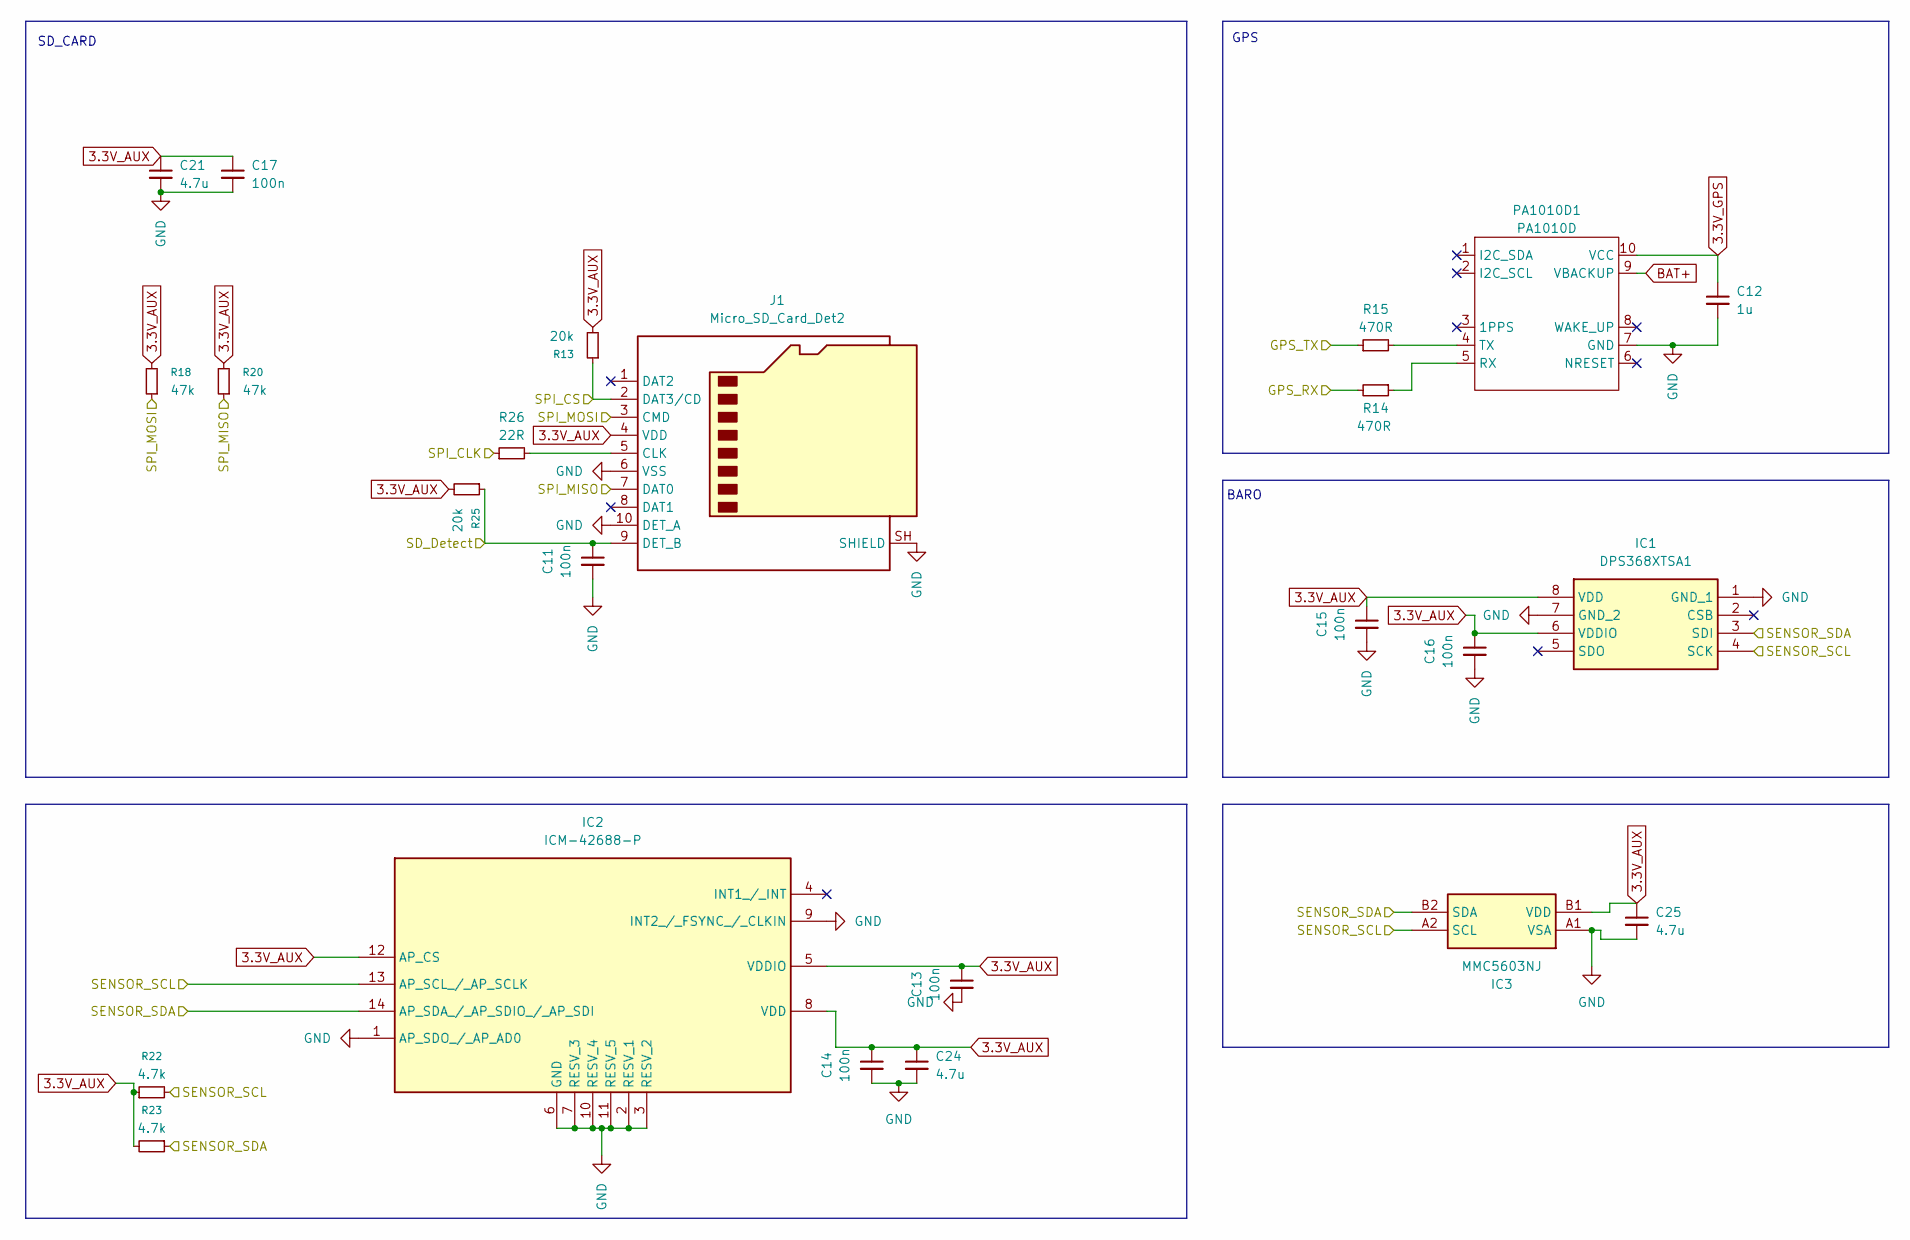
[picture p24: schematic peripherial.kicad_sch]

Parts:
C11, C13, C14, C15, C16, C17: 100n; C_0201_0603Metric_Pad0.64x0.40mm_HandSolder
C12: 1u; C_0201_0603Metric_Pad0.64x0.40mm_HandSolder
C21, C24, C25: 4.7u; C_0402_1005Metric
IC1: DPS368XTSA1; Mouser Part Number 726-DPS368XTSA1
IC2: ICM-42688-P; IIM42352; Manufacturer_Part_Number ICM-42688-P; Mouser Part Number 410-ICM-42688-P
IC3: MMC5603NJ; Manufacturer_Part_Number MMC5603NJ; Mouser Part Number 438-MMC5603NJ
J1: Micro_SD_Card_Det2; microSD_HC_Molex_104031-0811
PA1010D1: PA1010D
R13, R25: 20k; R_0201_0603Metric_Pad0.64x0.40mm_HandSolder; Mouser Part Number 603-AC0201FR-0720KL
R14, R15: 470R; R_0201_0603Metric_Pad0.64x0.40mm_HandSolder
R18, R20: 47k; R_0201_0603Metric_Pad0.64x0.40mm_HandSolder; Mouser Part Number 603-AC0201FR-0720KL
R22, R23: 4.7k; R_0201_0603Metric_Pad0.64x0.40mm_HandSolder; Mouser Part Number 603-AC0201FR-0720KL
R26: 22R; R_0201_0603Metric_Pad0.64x0.40mm_HandSolder

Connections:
3.3V_AUX: C13.1, C14.1, C15.1, C16.1, C17.1, C21.1, C24.1, C25.1, IC1.6 (VDDIO), IC1.8 (VDD), IC2.5 (VDDIO), IC2.8 (VDD), IC2.12 (AP_CS), IC3.B1 (VDD), J1.4 (VDD), R13.2, R18.2, R20.2, R22.1, R23.2, R25.2; also elsewhere on the board
3.3V_GPS: C12.1, PA1010D1.10 (VCC); also elsewhere on the board
/GPS_RX: R14.2; also elsewhere on the board
/GPS_TX: R15.1; also elsewhere on the board
/SD_DET: C11.1, J1.9 (DET_B), R25.1; also elsewhere on the board
/SENSOR_SCL: IC1.4 (SCK), IC2.13 (AP_SCL_/_AP_SCLK), IC3.A2 (SCL), R22.2; also elsewhere on the board
/SENSOR_SDA: IC1.3 (SDI), IC2.14 (AP_SDA_/_AP_SDIO_/_AP_SDI), IC3.B2 (SDA), R23.1; also elsewhere on the board
/SPI_CLK: R26.1; also elsewhere on the board
/SPI_CS: J1.2 (DAT3/CD), R13.1; also elsewhere on the board
/SPI_MISO: J1.7 (DAT0), R20.1; also elsewhere on the board
/SPI_MOSI: J1.3 (CMD), R18.1; also elsewhere on the board
BAT+: PA1010D1.9 (VBACKUP); also elsewhere on the board
GND: C11.2, C12.2, C13.2, C14.2, C15.2, C16.2, C17.2, C21.2, C24.2, C25.2, IC1.1 (GND_1), IC1.7 (GND_2), IC2.1 (AP_SDO_/_AP_AD0), IC2.2 (RESV_1), IC2.3 (RESV_2), IC2.6 (GND), IC2.7 (RESV_3), IC2.9 (INT2_/_FSYNC_/_CLKIN), IC2.10 (RESV_4), IC2.11 (RESV_5), IC3.A1 (VSA), J1.6 (VSS), J1.10 (DET_A), J1.SH (SHIELD), PA1010D1.7 (GND); also elsewhere on the board
unnamed: J1.5 (CLK), R26.2
unnamed: PA1010D1.5 (RX), R14.1
unnamed: PA1010D1.4 (TX), R15.2

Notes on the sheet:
SD_CARD
BARO
GPS

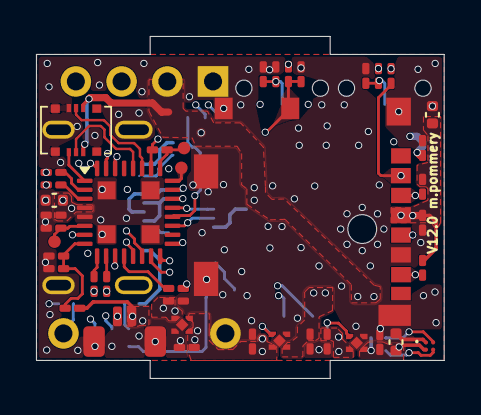
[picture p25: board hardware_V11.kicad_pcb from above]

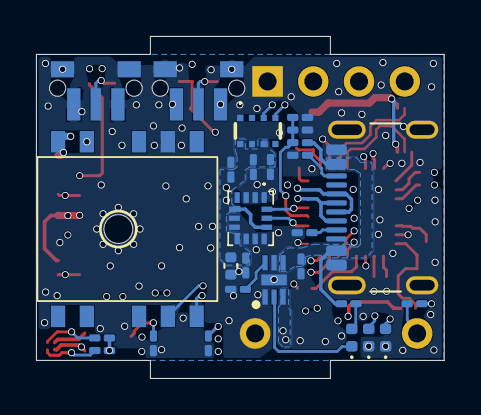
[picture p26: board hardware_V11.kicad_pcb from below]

Board: 6 copper layers, 22.7 x 19.0 mm, 71 parts (29 on the bottom side), 45 nets.

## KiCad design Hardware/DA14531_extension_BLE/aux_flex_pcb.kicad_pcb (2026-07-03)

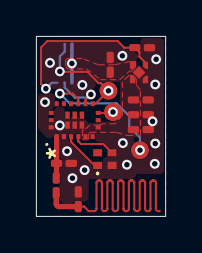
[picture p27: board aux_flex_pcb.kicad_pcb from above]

Board: 2 copper layers, 7.2 x 10.0 mm, 15 parts (1 on the bottom side), 11 nets.

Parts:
C21, C26, C27: 1u; C_0201_0603Metric_Pad0.64x0.40mm_HandSolder
C22, C23: 3.3nF; C_0201_0603Metric_Pad0.64x0.40mm_HandSolder
C25: 100n; C_0201_0603Metric_Pad0.64x0.40mm_HandSolder
J4: 503552-0622; 5035520622
L2: 1.8nH; L_0201_0603Metric_Pad0.64x0.40mm_HandSolder
R22: 100k; R_0201_0603Metric_Pad0.64x0.40mm_HandSolder
TP6: swdio; 1mm_circle
TP7: swclk; 1mm_circle
TP8: rst; 1mm_circle
U1: ldln025pu
U2: DA14531-00000FX2; FCGQFN24_2.2X3.0_REN
Y1: 830108254201

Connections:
3.3V_AUX: C27.1, J4.1, J4.6, U1.4 (VIN)
/RF: C22.1, L2.1, U2.1 (RFIOp)
/SWCLK: TP7.1 (1_1), U2.12 (P0_2)
/SWDIO: TP6.1 (1_1), U2.9 (P0_10)
/exti: J4.3, R22.2, U1.3 (EN)
/rx_sup: J4.5, TP8.1 (1_1), U2.10 (RST/P0_0)
/tx_sup: J4.2, U2.11 (P0_1)
GND: C21.2, C22.2, C23.2, C25.2, C26.2, C27.2, J4.4, J4.MP1, J4.MP2, J4.MP3, J4.MP4, R22.1, U1.2 (GND), U2.2 (GNDRF2), U2.18 (RFIOm), U2.19 (GNDRF1), U2.20 (GND), U2.21 (GND_DCDC), U2.23 (VSS), Y1.2 (GND(LID))
unnamed: C21.1, C25.1, C26.1, U1.1 (VOUT), U2.5 (VBAT_LOW), U2.7 (VBAT_HIGH)
unnamed: U2.4 (XTAL32Mm), Y1.3 (CRYSTAL_2)
unnamed: U2.3 (XTAL32Mp), Y1.1 (CRYSTAL_1)

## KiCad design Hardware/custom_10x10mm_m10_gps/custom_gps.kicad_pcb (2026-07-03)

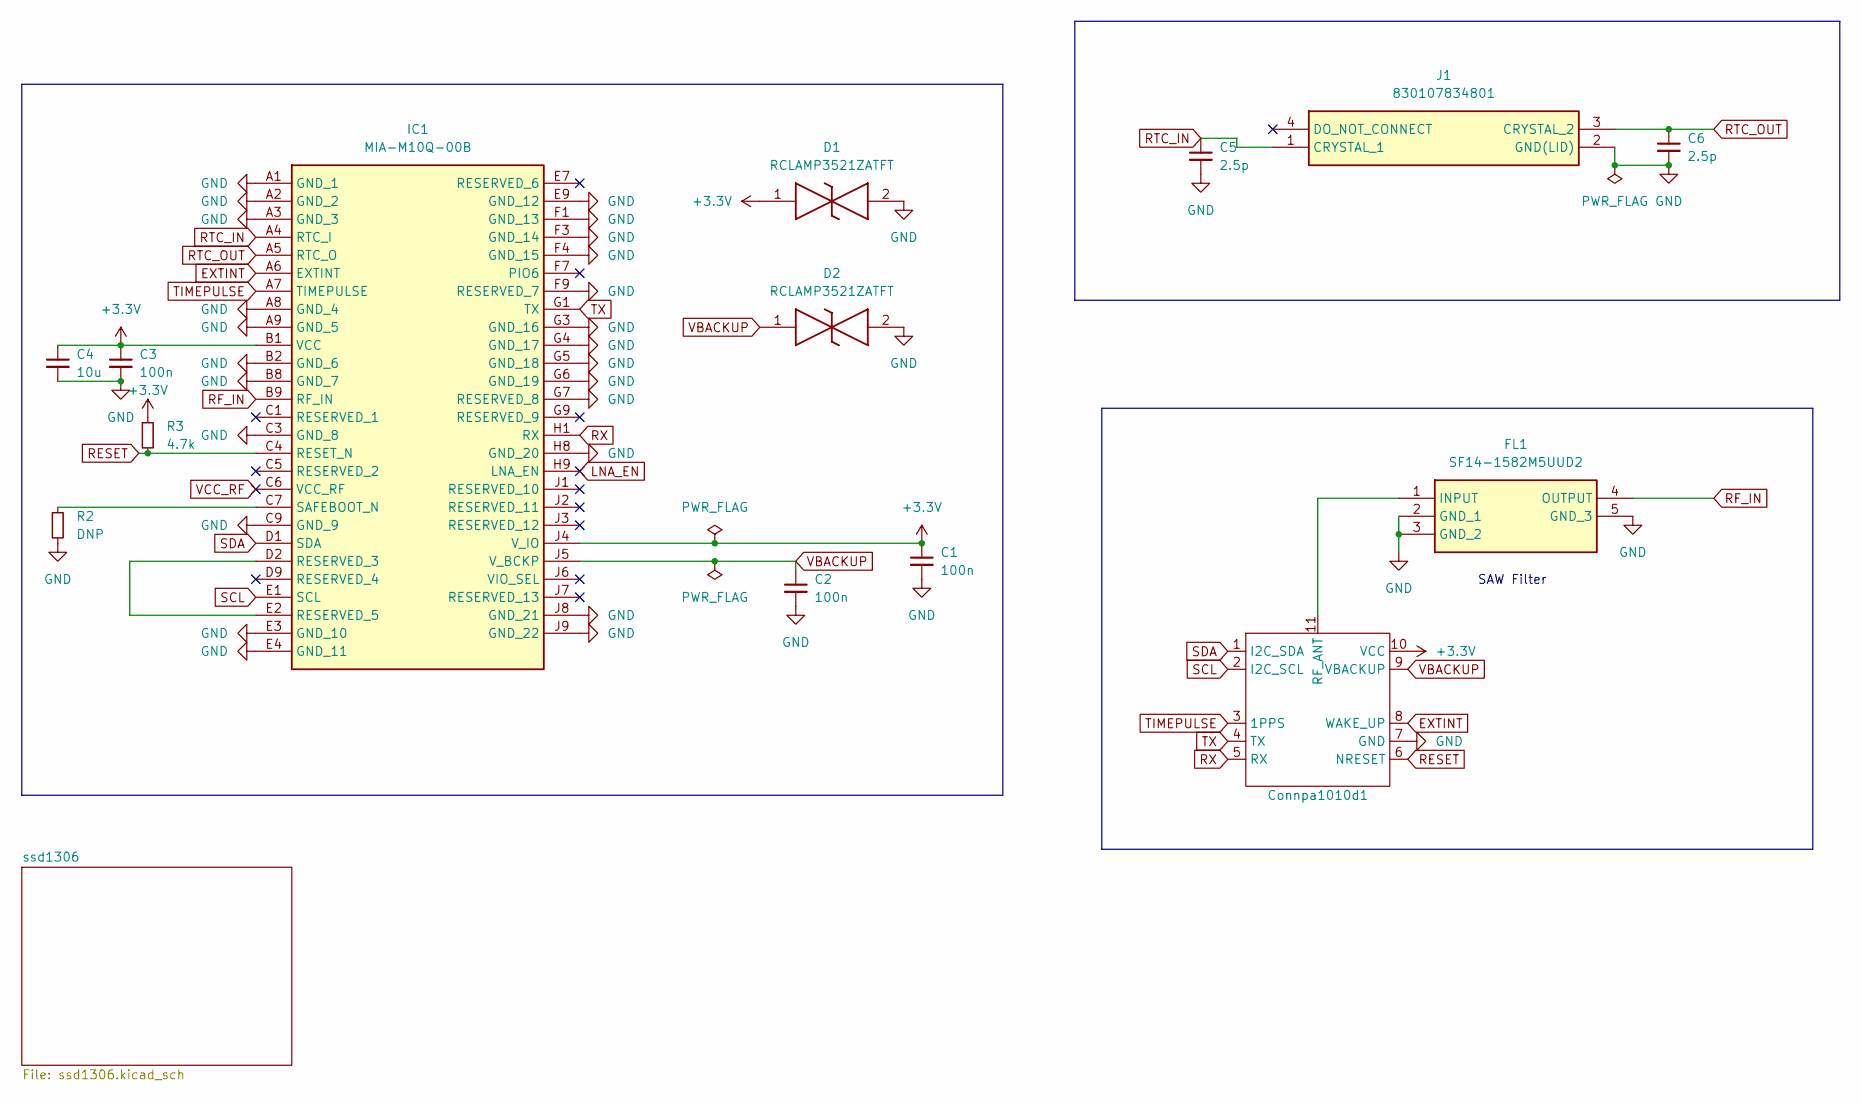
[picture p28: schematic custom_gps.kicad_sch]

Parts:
C1, C2, C3: 100n; C_0201_0603Metric
C4: 10u; C_0402_1005Metric
C5, C6: 2.5p; C_0201_0603Metric
Connpa1010d1: PA1010D
D1, D2: RCLAMP3521ZATFT; Mouser Part Number 947-RCLAMP3521ZATFT
FL1: SF14-1582M5UUD2; SF141582M5UUD2; Mouser Part Number 581-SF14-1582M5UUD2
IC1: MIA-M10Q-00B; MIAM10Q00B; Mouser Part Number 377-MIA-M10Q-00B
J1: 830107834801; Mouser Part Number 710-830107834801
R2: DNP; R_0201_0603Metric
R3: 4.7k; R_0201_0603Metric

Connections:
+3.3V: C1.1, C3.1, C4.1, Connpa1010d1.10 (VCC), D1.1, IC1.B1 (VCC), IC1.J4 (V_IO), R3.1
EXTINT: Connpa1010d1.8 (WAKE_UP), IC1.A6 (EXTINT)
GND: C1.2, C2.2, C3.2, C4.2, C5.2, C6.2, Connpa1010d1.7 (GND), D1.2, D2.2, FL1.2 (GND_1), FL1.3 (GND_2), FL1.5 (GND_3), IC1.A1 (GND_1), IC1.A2 (GND_2), IC1.A3 (GND_3), IC1.A8 (GND_4), IC1.A9 (GND_5), IC1.B2 (GND_6), IC1.B8 (GND_7), IC1.C3 (GND_8), IC1.C9 (GND_9), IC1.E3 (GND_10), IC1.E4 (GND_11), IC1.E9 (GND_12), IC1.F1 (GND_13), IC1.F3 (GND_14), IC1.F4 (GND_15), IC1.F9 (RESERVED_7), IC1.G3 (GND_16), IC1.G4 (GND_17), IC1.G5 (GND_18), IC1.G6 (GND_19), IC1.G7 (RESERVED_8), IC1.H8 (GND_20), IC1.J8 (GND_21), IC1.J9 (GND_22), J1.2 (GND(LID)), R2.2
LNA_EN: IC1.H9 (LNA_EN)
unnamed: Connpa1010d1.11 (RF_ANT), FL1.1 (INPUT)
unnamed: IC1.D2 (RESERVED_3), IC1.E2 (RESERVED_5)
unnamed: IC1.C7 (SAFEBOOT_N), R2.1
RESET: Connpa1010d1.6 (NRESET), IC1.C4 (RESET_N), R3.2
RF_IN: FL1.4 (OUTPUT), IC1.B9 (RF_IN)
RTC_IN: C5.1, IC1.A4 (RTC_I), J1.1 (CRYSTAL_1)
RTC_OUT: C6.1, IC1.A5 (RTC_O), J1.3 (CRYSTAL_2)
RX: Connpa1010d1.5 (RX), IC1.H1 (RX)
SCL: Connpa1010d1.2 (I2C_SCL), IC1.E1 (SCL)
SDA: Connpa1010d1.1 (I2C_SDA), IC1.D1 (SDA)
TIMEPULSE: Connpa1010d1.3 (1PPS), IC1.A7 (TIMEPULSE)
TX: Connpa1010d1.4 (TX), IC1.G1 (TX)
VBACKUP: C2.1, Connpa1010d1.9 (VBACKUP), D2.1, IC1.J5 (V_BCKP)
VCC_RF: IC1.C6 (VCC_RF)

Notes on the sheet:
SAW Filter

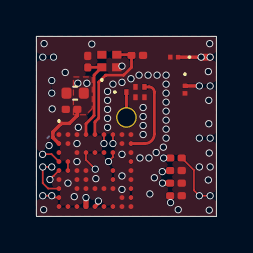
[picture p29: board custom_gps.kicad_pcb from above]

Board: 6 copper layers, 10.0 x 10.0 mm, 14 parts (1 on the bottom side), 16 nets.

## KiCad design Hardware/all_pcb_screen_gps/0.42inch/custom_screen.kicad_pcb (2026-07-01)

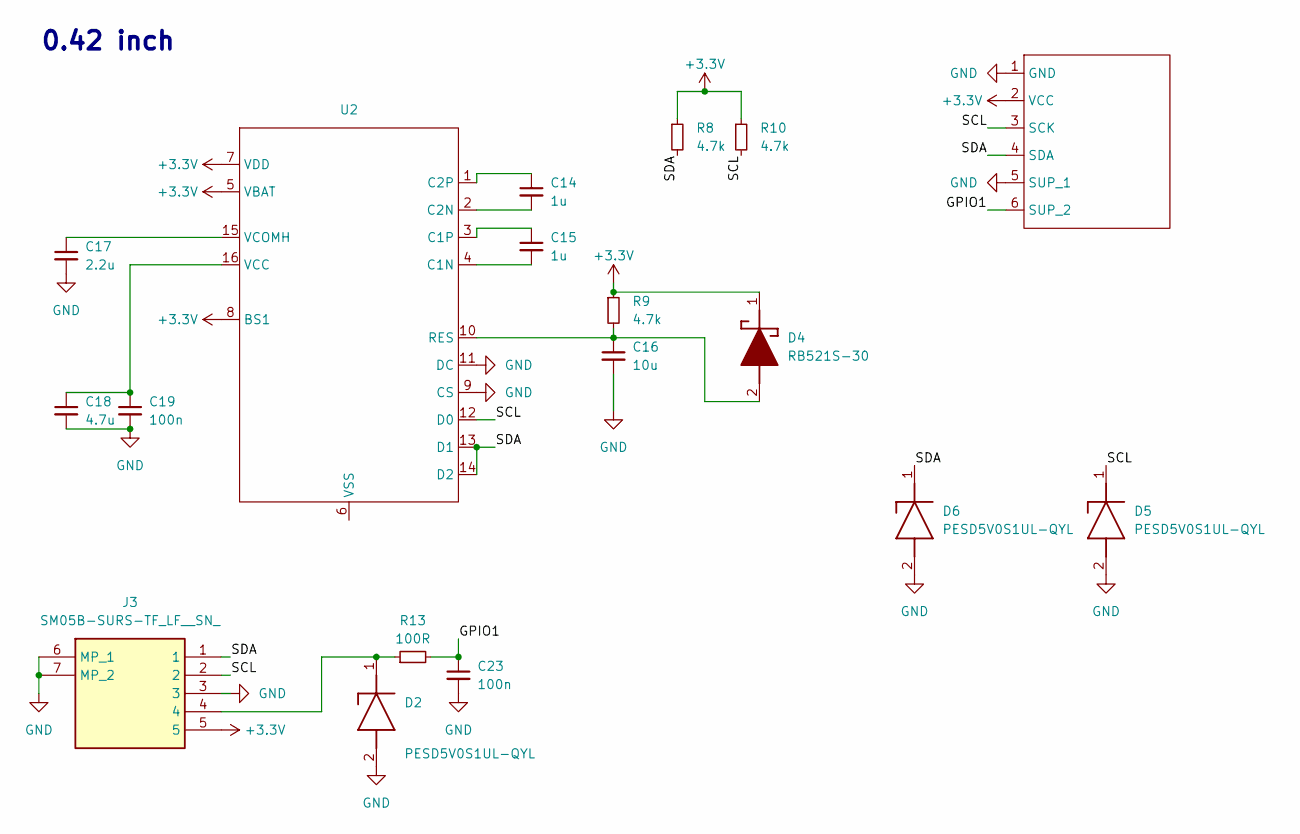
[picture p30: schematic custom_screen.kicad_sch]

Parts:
C14, C15: 1u; C_0201_0603Metric
C16: 10u; C_0402_1005Metric
C17: 2.2u; C_0402_1005Metric
C18: 4.7u; C_0402_1005Metric
C19, C23: 100n; C_0201_0603Metric
D2, D5, D6: PESD5V0S1UL-QYL; PESD5V0S1ULQYL; Manufacturer_Part_Number PESD5V0S1UL-QYL; Mouser Part Number 771-PESD5V0S1UL-QYL
D4: RB521S-30; SODFL1608X70N; Manufacturer_Part_Number RB521S-30
J3: SM05B-SURS-TF_LF__SN_; SM05BSURSTFLFSN; Manufacturer_Part_Number SM05B-SURS-TF(LF)(SN); Mouser Part Number 306-SM05BSURSTFLFSN
R8, R9, R10: 4.7k; R_0201_0603Metric
R13: 100R; R_0201_0603Metric
U2: ssd1306_0.42_fpc
U5: ssd1306_5point

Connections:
+3.3V: D4.1 (K), J3.5, R8.1, R9.1, R10.1, U2.5 (VBAT), U2.7 (VDD), U2.8 (BS1), U5.2 (VCC)
/GPIO1: C23.1, R13.2, U5.6 (SUP_2)
/SCL: D5.1 (K), J3.2, R10.2, U2.12 (D0), U5.3 (SCK)
/SDA: D6.1 (K), J3.1, R8.2, U2.13 (D1), U2.14 (D2), U5.4 (SDA)
GND: C16.2, C17.2, C18.2, C19.2, C23.2, D2.2 (A), D5.2 (A), D6.2 (A), J3.3, J3.6 (MP_1), J3.7 (MP_2), U2.9 (CS), U2.11 (DC), U5.1 (GND), U5.5 (SUP_1)
unnamed: D2.1 (K), J3.4, R13.1
unnamed: C16.1, D4.2 (A), R9.2, U2.10 (RES)
unnamed: C15.2, U2.4 (C1N)
unnamed: C15.1, U2.3 (C1P)
unnamed: C14.2, U2.2 (C2N)
unnamed: C14.1, U2.1 (C2P)
unnamed: C18.1, C19.1, U2.16 (VCC)
unnamed: C17.1, U2.15 (VCOMH)

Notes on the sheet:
0.42 inch

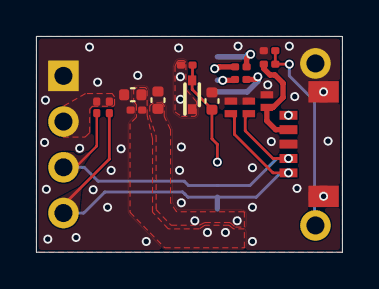
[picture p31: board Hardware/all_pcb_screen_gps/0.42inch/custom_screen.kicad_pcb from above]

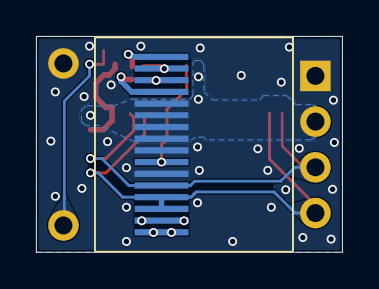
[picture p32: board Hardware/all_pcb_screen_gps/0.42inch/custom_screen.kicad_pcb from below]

Board: 2 copper layers, 17.0 x 12.0 mm, 18 parts (2 on the bottom side), 13 nets.

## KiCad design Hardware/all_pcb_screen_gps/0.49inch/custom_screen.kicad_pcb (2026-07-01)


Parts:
C7: 4.7u; C_0402_1005Metric
C8, C22: 100n; C_0201_0603Metric
C9, C10: 1u; C_0201_0603Metric
C11, C12: 10u; C_0402_1005Metric
D1, D7, D8: PESD5V0S1UL-QYL; PESD5V0S1ULQYL; Manufacturer_Part_Number PESD5V0S1UL-QYL; Mouser Part Number 771-PESD5V0S1UL-QYL
D9: RB521S-30; SODFL1608X70N; Manufacturer_Part_Number RB521S-30
J2: SM05B-SURS-TF_LF__SN_; SM05BSURSTFLFSN; Manufacturer_Part_Number SM05B-SURS-TF(LF)(SN); Mouser Part Number 306-SM05BSURSTFLFSN
R4, R5, R7: 4.7k; R_0201_0603Metric
R6: 560k; R_0201_0603Metric
R12: 100R; R_0201_0603Metric
U1: ssd1306_fpc
U4: ssd1306_5point

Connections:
+3.3V: D9.1 (K), J2.5, R4.1, R5.1, R7.1, U1.5 (VBAT), U1.8 (VDD), U4.2 (VCC)
/GPIO2: C22.1, R12.2, U4.6 (SUP_2)
/SCL: D8.1 (K), J2.2, R5.2, U1.10 (SCL), U4.3 (SCK)
/SDA: D7.1 (K), J2.1, R4.2, U1.11 (SDA), U4.4 (SDA)
GND: C7.2, C8.2, C11.2, C12.2, C22.2, D1.2 (A), D7.2 (A), D8.2 (A), J2.3, J2.6 (MP_1), J2.7 (MP_2), R6.2, U1.7 (VSS), U4.1 (GND), U4.5 (SUP_1)
unnamed: D1.1 (K), J2.4, R12.1
unnamed: C12.1, D9.2 (A), R7.2, U1.9 (RES)
unnamed: C10.2, U1.4 (C1N)
unnamed: C10.1, U1.3 (C1P)
unnamed: C9.2, U1.2 (C2N)
unnamed: C9.1, U1.1 (C2P)
unnamed: R6.1, U1.12 (IREF)
unnamed: C7.1, C8.1, U1.14 (VCC)
unnamed: C11.1, U1.13 (VCOMH)

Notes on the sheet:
0.49 inch



Board: 2 copper layers, 17.0 x 12.0 mm, 19 parts (17 on the bottom side), 14 nets.

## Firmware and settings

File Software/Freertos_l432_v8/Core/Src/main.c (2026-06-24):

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
/* Includes ------------------------------------------------------------------*/
#include "main.h"
#include "cmsis_os.h"
#include "adc.h"
#include "dma.h"
#include "fatfs.h"
#include "i2c.h"
#include "usart.h"
#include "spi.h"
#include "usb_device.h"
#include "gpio.h"

/* USER CODE BEGIN Includes */
#include "ssd1306.h"
#include "statemachine.h"
#include "GNSS.h"
#include "pwr.h"
#include "sd_app.h"

/* USER CODE END Includes */


/* USER CODE BEGIN PV */

AppStateMachineContext state_struct = { .state = STATE_SPEED, .spdstate =
		STATE_GROS, .balisestate = BALISESTATE1,
		.ecranstate = ECRANBALISESTATE1, .posstate = STATE_SUMMARY1,
};

GNSS_StateHandle GNSSData;
Buttons_t gButtons = { 0 };
AdcContext_t gAdc = { 0 };
uint8_t bufferscreen[50];
uint32_t lat_index[182] = {0};
uint32_t lat_index_mountain[182] = {0};
SDCard_struct sdcard;


/* USER CODE END PV */

void SystemClock_Config(void);
void MX_FREERTOS_Init(void);
/* USER CODE BEGIN 0 */

void HAL_GPIO_EXTI_Callback(uint16_t GPIO_Pin) {
	/* -------------------- BTN_A sur PA15 -------------------- */
	if (GPIO_Pin == B2_Pin) {
		if (HAL_GPIO_ReadPin(B2_GPIO_Port, B2_Pin) == GPIO_PIN_SET) {
			gButtons.pressStart_B_ms = HAL_GetTick();
		} else {
			uint32_t now = HAL_GetTick();
			uint32_t dur = 0;

			if (gButtons.pressStart_B_ms != 0) {
				dur = now - gButtons.pressStart_B_ms;

				gButtons.time_B_ms = dur;
				gButtons.pressStart_B_ms = 0;

				if (dur >= 50 && dur <= 400) {
					gButtons.BTN_B = 1;
					gButtons.BTN_B_LONG = 0;
				} else if (dur >= 400) {
					gButtons.BTN_B_LONG = 1;
					gButtons.BTN_B = 0;
				} else {
					gButtons.BTN_B = 0;
					gButtons.BTN_B_LONG = 0;
				}
			}
		}
	}

	/* -------------------- BTN_PW sur PA0 -------------------- */
	if (GPIO_Pin == PWR_BTN_Pin) {
		if (HAL_GPIO_ReadPin(PWR_BTN_GPIO_Port, PWR_BTN_Pin)
				== GPIO_PIN_RESET) {
			gButtons.PW_BTN_FALLING_FLAG = 1;

		} else {
			gButtons.PW_BTN_RISING_FLAG = 1;
		}
	}
}

void HAL_ADC_ConvCpltCallback(ADC_HandleTypeDef *hadc) {
	if (hadc->Instance == ADC1) {
		const float vref_cal = (float) STM32L432_VREFINT_CAL();
		const float ts_cal1 = (float) STM32L432_TS_CAL1();
		const float ts_cal2 = (float) STM32L432_TS_CAL2();

		const float adc_vref = (float) gAdc.raw[0];
		const float adc_ts = (float) gAdc.raw[1];
		const float adc_vbat = (float) gAdc.raw[2];

		gAdc.vrefint = (STM32L432_VDDA_CAL_V * vref_cal) / adc_vref;

		const float ts_data_3v = (adc_ts * vref_cal) / adc_vref;

		gAdc.temp = ((ts_data_3v - ts_cal1)
				* (STM32L432_TS_CAL2_TEMP_C - STM32L432_TS_CAL1_TEMP_C)
				/ (ts_cal2 - ts_cal1)) + STM32L432_TS_CAL1_TEMP_C;

		gAdc.vbat = 2.0f * (adc_vbat / 4095.0f) * gAdc.vrefint;
	}

}

void HAL_UART_RxHalfCpltCallback(UART_HandleTypeDef *huart) {
	if (huart->Instance == LPUART1) {
		GNSSData.write_index = 256;

	}
}

void HAL_UART_RxCpltCallback(UART_HandleTypeDef *huart) {
	if (huart->Instance == LPUART1) {
		GNSSData.write_index = 0;
	}
}

#ifdef USE_FAST_PRINT

void fast_printf(char *buf, const char *text, float val, ValType type,
		int precision, PosType pos) {
	// 1. Si le texte est un préfixe, on l'écrit d'abord
	if (pos == POS_PREFIX && text != NULL) {
		while (*text)
			*buf++ = *text++;
	}

	// 2. Écriture de la valeur
	if (type == TYPE_INT) {
		int32_t v = (int32_t) val;
		if (v == 0) {
			*buf++ = '0';
		} else {
			if (v < 0) {
				*buf++ = '-';
				v = -v;
			}
			char temp[12];
			int i = 0;
			while (v > 0) {
				temp[i++] = (v % 10) + '0';
				v /= 10;
			}
			while (i > 0)
				*buf++ = temp[--i];
		}
	} else {
		int32_t int_part = (int32_t) val;
		if (val < 0) {
			*buf++ = '-';
			val = -val;
			int_part = (int32_t) val;
		}

		if (int_part == 0) {
			*buf++ = '0';
		} else {
			char temp[12];
			int i = 0;
			while (int_part > 0) {
				temp[i++] = (int_part % 10) + '0';
				int_part /= 10;
			}
			while (i > 0)
				*buf++ = temp[--i];
		}

		*buf++ = '.';
		float frac = val - (int32_t) val;
		for (int i = 0; i < precision; i++) {
			frac *= 10;
			int digit = (int) frac;
			*buf++ = digit + '0';
			frac -= digit;
		}
	}

	// 3. Si le texte est un suffixe, on l'écrit après
	if (pos == POS_SUFFIX && text != NULL) {
		while (*text)
			*buf++ = *text++;
	}

	*buf = '\0';
}

#endif

/* USER CODE END 0 */

/**
  * @brief  The application entry point.
  * @retval int
  */
int main(void)
{

  /* MCU Configuration--------------------------------------------------------*/

  /* Reset of all peripherals, Initializes the Flash interface and the Systick. */
  HAL_Init();

  /* USER CODE BEGIN Init */

#ifndef DEBUG1
	PWR_StartupCheckButton();
#endif
  /* USER CODE END Init */

  /* Configure the system clock */
  SystemClock_Config();

  /* Initialize all configured peripherals */
  MX_GPIO_Init();
  MX_DMA_Init();
  MX_I2C1_Init();
  MX_LPUART1_UART_Init();
  MX_SPI1_Init();
  MX_ADC1_Init();
  MX_FATFS_Init();
  /* USER CODE BEGIN 2 */

	HAL_GPIO_WritePin(AUX_EN_GPIO_Port, AUX_EN_Pin, GPIO_PIN_SET);
	HAL_GPIO_WritePin(GPS_EN_GPIO_Port, GPS_EN_Pin, GPIO_PIN_SET);

	HAL_Delay(10);
	ssd1306_Init();
	HAL_Delay(10);
	ssd1306_Fill(Black);

	ssd1306_DrawBitmap(32, 32, startimg, 64, 32, White);
	ssd1306_UpdateScreen();

	HAL_ADC_Start_DMA(&hadc1, (uint32_t*) gAdc.raw, 3);

	GNSS_Init(&GNSSData, &hlpuart1);
	HAL_UART_Abort(&hlpuart1);
	HAL_UART_Receive_DMA(&hlpuart1, (uint8_t*) GNSSData.circular_buffer, 512);
	__HAL_DMA_ENABLE_IT(hlpuart1.hdmarx, DMA_IT_HT);

	Init_Sd(&sdcard);


#ifdef DEBUG1
	    CoreDebug->DEMCR |= CoreDebug_DEMCR_TRCENA_Msk;
	    DWT->CYCCNT = 0;
	    DWT->CTRL |= DWT_CTRL_CYCCNTENA_Msk;
#endif
	HAL_Delay(200);
	ssd1306_Fill(Black);

  /* USER CODE END 2 */

  /* Call init function for freertos objects (in cmsis_os2.c) */
  MX_FREERTOS_Init();

  /* Start scheduler */
  osKernelStart();

  /* We should never get here as control is now taken by the scheduler */

  /* Infinite loop */
  /* USER CODE BEGIN WHILE */
	while (1) {
    /* USER CODE END WHILE */

    /* USER CODE BEGIN 3 */
	}
  /* USER CODE END 3 */
}

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
/**
  * @brief  Period elapsed callback in non blocking mode
  * @note   This function is called  when TIM1 interrupt took place, inside
  * HAL_TIM_IRQHandler(). It makes a direct call to HAL_IncTick() to increment
  * a global variable "uwTick" used as application time base.
  * @param  htim : TIM handle
  * @retval None
  */
void HAL_TIM_PeriodElapsedCallback(TIM_HandleTypeDef *htim)
{
  if (htim->Instance == TIM1)
  {
    HAL_IncTick();
  }
}

/**
  * @brief  This function is executed in case of error occurrence.
  * @retval None
  */
void Error_Handler(void)
{
  /* USER CODE BEGIN Error_Handler_Debug */
	/* User can add his own implementation to report the HAL error return state */
	__disable_irq();
	while (1) {
	}
  /* USER CODE END Error_Handler_Debug */
}
#ifdef USE_FULL_ASSERT
/**
  * @brief  Reports the name of the source file and the source line number
  *         where the assert_param error has occurred.
  * @param  file: pointer to the source file name
  * @param  line: assert_param error line source number
  * @retval None
  */
void assert_failed(uint8_t *file, uint32_t line)
{
  /* USER CODE BEGIN 6 */
  /* User can add his own implementation to report the file name and line number,
     ex: printf("Wrong parameters value: file %s on line %d\r\n", file, line) */
  /* USER CODE END 6 */
}
#endif /* USE_FULL_ASSERT */

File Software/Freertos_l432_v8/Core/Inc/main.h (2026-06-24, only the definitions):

#define GPS_EN_Pin GPIO_PIN_15
#define GPS_EN_GPIO_Port GPIOC
#define PWR_BTN_Pin GPIO_PIN_0
#define PWR_BTN_GPIO_Port GPIOA
#define PWR_BTN_EXTI_IRQn EXTI0_IRQn
#define FLASH_CS_Pin GPIO_PIN_4
#define FLASH_CS_GPIO_Port GPIOA
#define AUX_EN_Pin GPIO_PIN_1
#define AUX_EN_GPIO_Port GPIOB
#define USB_DET_Pin GPIO_PIN_8
#define USB_DET_GPIO_Port GPIOA
#define SD_DET_Pin GPIO_PIN_15
#define SD_DET_GPIO_Port GPIOA
#define LED_GREEN_Pin GPIO_PIN_4
#define LED_GREEN_GPIO_Port GPIOB
#define LED_BLUE_Pin GPIO_PIN_5
#define LED_BLUE_GPIO_Port GPIOB
#define B2_Pin GPIO_PIN_3
#define B2_GPIO_Port GPIOH
#define B2_EXTI_IRQn EXTI3_IRQn
#define STM32L432_VREFINT_CAL_ADDR   ((volatile uint16_t*)0x1FFF75AAu)
#define STM32L432_TS_CAL1_ADDR       ((volatile uint16_t*)0x1FFF75A8u)
#define STM32L432_TS_CAL2_ADDR       ((volatile uint16_t*)0x1FFF75CAu)
#define STM32L432_VDDA_CAL_V         (3.0f)
#define STM32L432_TS_CAL1_TEMP_C     (30.0f)
#define STM32L432_TS_CAL2_TEMP_C     (130.0f)
#define SPI1_CS_Pin GPIO_PIN_4
#define SPI1_CS_GPIO_Port GPIOA
#define SD_SPI_HANDLE hspi1

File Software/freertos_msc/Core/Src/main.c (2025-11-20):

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
/* Includes ------------------------------------------------------------------*/
#include "main.h"
#include "cmsis_os.h"
#include "adc.h"
#include "dma.h"
#include "app_fatfs.h"
#include "i2c.h"
#include "ipcc.h"
#include "usart.h"
#include "rf.h"
#include "rtc.h"
#include "spi.h"
#include "tim.h"
#include "usb_device.h"
#include "gpio.h"

/* USER CODE BEGIN Includes */
#include "math.h"
#include "ssd1306.h"
#include "statemachine.h"
#include "stm32wbxx_hal.h"
#include "bmp581.h"
#include "GNSS.h"
#include "w25q.h"

/* USER CODE END Includes */


/* USER CODE BEGIN PV */
STATE_TYPE state=STATE_SPEED;
SPEED spdstate=STATE_GROS;
POS posstate=STATE_SUMMARY1;
CHRONO chronostate=STATE_RESET;
BALISESTATE balisestate=BALISESTATE1;
ACCELSTATE accelstate=WAITFORGPS;
uint8_t workingbuffer[110];
int BTN_A=0;
int BTN_B=0;



extern TIM_HandleTypeDef htim16;
extern TIM_HandleTypeDef htim17;

uint16_t rawdata[3];
float temp=0.0;
float vrefint=0;
float vbat=0;


uint8_t bufferscreen[50];
uint8_t longbufferscreen[256];
uint8_t usbbuffer[64];
uint16_t offsetforscroltext=0;
uint16_t scrolltextmax=0;

float vitmax=0.0;
float seconde=0;
float min=0;

uint32_t starttime=0;
uint32_t calctime=0;
uint32_t timehandler=0;
float t1=0;
float t2=0;
float t3=0;
float moy=0;
float framerate=0;


int doubledonnee=0;
int cptdoubledonnee=0;
double distanceparcouru=0;
double oldlat=0;
double oldlong=0;




float altibaro=0;


uint8_t SEC=0;
uint8_t HR=0;
uint8_t MINUTE=0;
uint8_t JOURS=10;
uint8_t MOIS=11;
uint16_t ANNEE=2024;
int settimeen=0;


int boutonAtime=0;
int boutonBtime=0;
int tbtn1=0;
int tbtn2=0;
int BTN_B_LONG=0;
int BTN_A_LONG=0;


ECRANBALISESTATE ecranstate=ECRANBALISESTATE1;

BMP_t * bmp581;
GNSS_StateHandle GNSSData;
SPIF_HandleTypeDef hspif1;

int received_flag=0;

int modesansechec=0;

int flag_usb_mounted=0;


const unsigned char startimg[] = {
0x00, 0x00, 0x00, 0x00, 0x00, 0x00, 0x00, 0x00,
0x7f, 0xff, 0xff, 0xff, 0xff, 0xff, 0xff, 0xfe,
0x7f, 0xff, 0xff, 0xff, 0xff, 0xff, 0xfe, 0x3e,
0x7f, 0xff, 0xff, 0xff, 0xff, 0xff, 0xf9, 0xce,
0x7f, 0xff, 0xff, 0xff, 0xff, 0xff, 0xfa, 0x2e,
0x7f, 0xfc, 0x1f, 0xff, 0xff, 0xff, 0xf6, 0xb6,
0x7f, 0xf0, 0x07, 0xff, 0xff, 0xff, 0xf6, 0x76,
0x7f, 0xc0, 0x01, 0xff, 0xff, 0xff, 0xfa, 0xae,
0x7f, 0x80, 0x00, 0xff, 0xff, 0xff, 0xf9, 0xce,
0x7f, 0x81, 0xc0, 0xff, 0xff, 0xff, 0xfe, 0x3e,
0x7f, 0x03, 0xe0, 0x7f, 0xff, 0xff, 0xff, 0xfe,
0x7f, 0x07, 0xf0, 0x7f, 0x0f, 0x03, 0xf0, 0x3e,
0x7f, 0x07, 0xf0, 0x7f, 0x0f, 0x03, 0xf0, 0x3e,
0x7f, 0x07, 0xf0, 0x7c, 0xff, 0x3c, 0xcf, 0xfe,
0x7f, 0x03, 0xe0, 0x7c, 0xff, 0x3c, 0xcf, 0xfe,
0x7f, 0x01, 0xc0, 0x7c, 0xc3, 0x03, 0xf0, 0xfe,
0x7f, 0x80, 0x00, 0xfc, 0xc3, 0x03, 0xf0, 0xfe,
0x7f, 0x80, 0x00, 0xfc, 0xf3, 0x3f, 0xff, 0x3e,
0x7f, 0xc0, 0x01, 0xfc, 0xf3, 0x3f, 0xff, 0x3e,
0x7f, 0xc0, 0x01, 0xff, 0x0f, 0x3f, 0xc0, 0xfe,
0x7f, 0xe0, 0x03, 0xff, 0x0f, 0x3f, 0xc0, 0xfe,
0x7f, 0xe0, 0x07, 0xff, 0xff, 0xff, 0xff, 0xfe,
0x7f, 0xf0, 0x07, 0xff, 0xff, 0xff, 0xff, 0xfe,
0x7f, 0xf0, 0x0f, 0xff, 0xff, 0x76, 0xfe, 0x7e,
0x7f, 0xf8, 0x0f, 0xff, 0xff, 0x74, 0xfd, 0xbe,
0x7f, 0xf8, 0x1f, 0xff, 0xff, 0xae, 0xfd, 0xbe,
0x7f, 0xfc, 0x1f, 0xff, 0xff, 0xae, 0xfd, 0xbe,
0x7f, 0xfc, 0x3f, 0xff, 0xff, 0xdc, 0x6e, 0x7e,
0x7f, 0xfe, 0x3f, 0xff, 0xff, 0xff, 0xff, 0xfe,
0x7f, 0xff, 0xff, 0xff, 0xff, 0xff, 0xff, 0xfe,
0x7f, 0xff, 0xff, 0xff, 0xff, 0xff, 0xff, 0xfe,
0x00, 0x00, 0x00, 0x00, 0x00, 0x00, 0x00, 0x00,
};

/* USER CODE END PV */

void SystemClock_Config(void);
void PeriphCommonClock_Config(void);
void MX_FREERTOS_Init(void);
/* USER CODE BEGIN 0 */
void HAL_GPIO_EXTI_Callback(uint16_t GPIO_Pin)//lors d'un appuie sur un bouton, le systeme s'interrompt afin d'arriver dans cette fonction redefinie avec en parametre d'entre , le bouton sur lequel l'on a appuiyé
{
	if(GPIO_Pin==GPIO_PIN_14){

		if(HAL_GPIO_ReadPin(GPIOC,GPIO_PIN_14)== GPIO_PIN_RESET){
					boutonAtime=0;
					tbtn1=HAL_GetTick();
				}
				else{
					boutonAtime=HAL_GetTick()-tbtn1;
					tbtn1=0;
				}


		if(boutonAtime>=50 && boutonAtime<=400){
			BTN_A++;
			BTN_A_LONG=0;
		}
		if(boutonAtime>=400){
			BTN_A_LONG++;
			BTN_A=0;
		}

	}
	if(GPIO_Pin==GPIO_PIN_15){

		if(HAL_GPIO_ReadPin(GPIOC,GPIO_PIN_15)== GPIO_PIN_RESET){
			boutonBtime=0;
			tbtn2=HAL_GetTick();
		}
		else{
			boutonBtime=HAL_GetTick()-tbtn2;
			tbtn2=0;
	}
		if(boutonBtime>=50 && boutonBtime<=400){
			BTN_B++;
			BTN_B_LONG=0;
		}
		if(boutonBtime>=400){
			BTN_B_LONG++;
			BTN_B=0;
		}



	}

}
/* USER CODE END 0 */

/**
  * @brief  The application entry point.
  * @retval int
  */
int main(void)
{

  /* MCU Configuration--------------------------------------------------------*/

  /* Reset of all peripherals, Initializes the Flash interface and the Systick. */
  HAL_Init();

  /* USER CODE BEGIN Init */

  GPIO_InitTypeDef GPIO_InitStruct = {0};
  void (*boot_jump)(void);

  __HAL_RCC_GPIOC_CLK_ENABLE();
   GPIO_InitStruct.Pin = GPIO_PIN_15|GPIO_PIN_14;
   GPIO_InitStruct.Mode = GPIO_MODE_INPUT;
   GPIO_InitStruct.Pull = GPIO_NOPULL;
   HAL_GPIO_Init(GPIOC, &GPIO_InitStruct);
   /* If both Select and Reset button held down at boot time, then immediately
    * jump to DFU bootloader, rather than start the Snickerdoodle application.
    */
   if ((HAL_GPIO_ReadPin(GPIOC, GPIO_PIN_14) == GPIO_PIN_RESET) &&
 	  (HAL_GPIO_ReadPin(GPIOC, GPIO_PIN_15) == GPIO_PIN_RESET))
   {
 	  HAL_DeInit();
 	  boot_jump = (void (*)(void))(*((uint32_t *)(SYS_MEM_START_ADDR + 4)));
 	  __set_MSP(*(__IO uint32_t*)SYS_MEM_START_ADDR);

 	  /* NOTE WELL: This call never returns: */
 	  boot_jump();
   }
   if(HAL_GPIO_ReadPin(GPIOC,GPIO_PIN_14)==GPIO_PIN_RESET){
	   modesansechec=1;
   }

  /* USER CODE END Init */

  /* Configure the system clock */
  SystemClock_Config();

  /* Configure the peripherals common clocks */
  PeriphCommonClock_Config();

  /* IPCC initialisation */
  MX_IPCC_Init();

  /* Initialize all configured peripherals */
  MX_GPIO_Init();
  MX_DMA_Init();
  MX_ADC1_Init();
  MX_I2C1_Init();
  MX_I2C3_Init();
  MX_LPUART1_UART_Init();
  MX_TIM2_Init();
  MX_TIM17_Init();
  MX_RTC_Init();
  MX_TIM16_Init();
  MX_SPI1_Init();
  if (MX_FATFS_Init() != APP_OK) {
    Error_Handler();
  }
  MX_RF_Init();
  /* USER CODE BEGIN 2 */

  	ssd1306_Init();
  	HAL_Delay(10);
  	ssd1306_Fill(Black);

  	ssd1306_DrawBitmap(32, 32, startimg, 64, 32, White);
  	ssd1306_UpdateScreen();


  	HAL_ADC_Start_DMA(&hadc1,(uint32_t*)rawdata, 3);
  	HAL_TIM_Base_Start(&htim2);

  	HAL_GPIO_WritePin(GPIOA,GPIO_PIN_0,GPIO_PIN_SET);
  	HAL_Delay(100);
  	GNSS_Init(&GNSSData, &hlpuart1);


  	HAL_UART_Abort(&hlpuart1);
  	HAL_UART_Receive_DMA(&hlpuart1, (uint8_t *)workingbuffer, 100);
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

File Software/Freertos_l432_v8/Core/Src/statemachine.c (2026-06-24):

/*
 * statemachine.c
 *
 * Created on: May 27, 2024
 * Author: mathi
 */

#include "statemachine.h"

extern uint8_t bufferscreen[50];
extern AdcContext_t gAdc;
extern uint32_t lat_index[182];
extern uint32_t lat_index_mountain[182];

static int8_t s_nav_pending = 0;

extern uint8_t Is_SD_Present(void);
extern uint8_t Is_Connected_To_PC(void);

void FindClosest(GNSS_StateHandle *gps, AppStateMachineContext *ctx,
		SDCard_struct *sd) {

	if (!Is_SD_Present() || Is_Connected_To_PC()) {
		return;
	}
	if (ctx->search_initialised == 0) {

		if (!sd->is_mounted) {
			if (f_mount(&sd->FatFs, "", 1) == FR_OK) {
				sd->is_mounted = 1;
			} else {
				return;
			}
		}

		UINT indexbytesRead;

		/* ---- Index VILLES ---- */
		if (f_open(&sd->f_villes, "INDEX.BIN", FA_READ) != FR_OK) {
			ctx->search_initialised = 2;
			return;
		}
		if (f_read(&sd->f_villes, lat_index, sizeof(uint32_t) * 182,
				&indexbytesRead) != FR_OK) {
			f_close(&sd->f_villes);
			ctx->search_initialised = 3;
			return;
		}
		f_close(&sd->f_villes);

		/* ---- Index MONTAGNES ---- */
		if (f_open(&sd->f_villes, "INDEXM.BIN", FA_READ) != FR_OK) {
			ctx->search_initialised = 4;
			return;
		}
		if (f_read(&sd->f_villes, lat_index_mountain, sizeof(uint32_t) * 182,
				&indexbytesRead) != FR_OK) {
			f_close(&sd->f_villes);
			ctx->search_initialised = 5;
			return;
		}
		f_close(&sd->f_villes);

		ctx->search_initialised = 1;
		return;
	}
	const char *filename;
	uint32_t *index_table;
	uint8_t is_mountain;

	if (ctx->searchstate == MOUNTAIN) {
		if (ctx->mountain_search_done == 1) {
			return;
		}
		filename = "MONTS.BIN";
		index_table = lat_index_mountain;
		is_mountain = 1;
	} else {
		if (ctx->city_search_done == 1) {
			return;
		}
		filename = "VILLES.BIN";
		index_table = lat_index;
		is_mountain = 0;
	}

	if (!sd->is_mounted) {
		if (f_mount(&sd->FatFs, "", 1) == FR_OK) {
			sd->is_mounted = 1;
		} else {
			return;
		}
	}

	UINT bytesRead;
	CityRecord current; /* meme layout 32 octets pour villes ET montagnes */
	float min_dist_sq = 999999999.0f;
	float cos_lat = cosf(gps->fLat * DEG_TO_RAD);

	if (f_open(&sd->f_villes, filename, FA_READ) == FR_OK) {

		int lat_deg = (int) floorf(gps->fLat);
		uint32_t offset_start = index_table[lat_deg + 90];
		uint32_t offset_end = index_table[lat_deg + 91];

		f_lseek(&sd->f_villes, offset_start);
		uint32_t current_offset = offset_start;

		while (current_offset < offset_end) {
			f_read(&sd->f_villes, &current, sizeof(CityRecord), &bytesRead);
			if (bytesRead != sizeof(CityRecord))
				break;

			float c_lat = (float) current.lat / 10000000.0f;
			float c_lon = (float) current.lon / 10000000.0f;

			float dx = (c_lon - gps->fLon) * cos_lat;
			float dy = (c_lat - gps->fLat);
			float dist_sq = (dx * dx) + (dy * dy);

			if (dist_sq < min_dist_sq) {
				min_dist_sq = dist_sq;

				/* Champs communs */
				strncpy(ctx->found_name, current.name, 17);
				ctx->found_lat = c_lat;
				ctx->found_lon = c_lon;
				ctx->found_name[17] = '\0';
				ctx->found_country[0] = current.country[0];
				ctx->found_country[1] = current.country[1];
				ctx->found_country[2] = '\0';
				ctx->found_dist_km = sqrtf(dist_sq) * 111.32f;

				/* Champ specifique au type (4e champ du record) */
				if (is_mountain) {
					ctx->mountain_alt = current.pop; /* = altitude en metres */
				} else {
					ctx->city_pop = current.pop; /* = population */
				}
			}
			current_offset += sizeof(CityRecord);
		}
		f_close(&sd->f_villes);
		if (is_mountain) {
			ctx->mountain_search_done = 1;
		} else {
			ctx->city_search_done = 1;
		}
	} else {
		if (is_mountain) {
			ctx->mountain_search_done = 1;
		} else {
			ctx->city_search_done = 1;
		}
	}
}

/* ===================================================================== */
/* GESTION GLOBALE DE LA NAVIGATION (BTN_A)                              */
/* ===================================================================== */

static void Nav_ChainOneStep(AppStateMachineContext *ctx) {
	int8_t dir = (s_nav_pending > 0) ? 1 : -1;
	s_nav_pending -= dir;

	uint8_t old_state = ctx->state;
	if (dir > 0) {
		ctx->state =
				(ctx->state == STATE_SETTINGS) ?
						STATE_SPEED : (uint8_t) (ctx->state + 1);
	} else {
		ctx->state =
				(ctx->state == STATE_SPEED) ?
						STATE_SETTINGS : (uint8_t) (ctx->state - 1);
	}
	ctx->city_search_done = 0;
	ScreenAnim_Start(old_state, ctx->state,
			(dir > 0) ? ANIM_DIR_NEXT : ANIM_DIR_PREV);
}

static void Handle_Global_Navigation(AppStateMachineContext *ctx,
		Buttons_t *buttons, SDCard_struct *sd) {

	if (ctx->state == STATE_SCREENSAVER)
		return;

	if (ctx->state == STATE_BALISE && sd->is_recording == 1) {
		buttons->BTN_A = 0;
		buttons->BTN_A_LONG = 0;
		return;
	}

	if (buttons->BTN_A >= 1) {
		uint8_t old_state = ctx->state;

		if (ctx->state == STATE_SETTINGS)
			ctx->state = STATE_SPEED;
		else
			ctx->state++;

		ctx->city_search_done = 0;
		buttons->BTN_A = 0;
		buttons->BTN_B = 0;

		ScreenAnim_Start(old_state, ctx->state, ANIM_DIR_NEXT); /* entre par la droite */
	}

	if (buttons->BTN_A_LONG >= 1) {
		uint8_t old_state = ctx->state;

		if (ctx->state == STATE_SPEED)
			ctx->state = STATE_SETTINGS;
		else
			ctx->state--;

		ctx->city_search_done = 0;
		buttons->BTN_A_LONG = 0;
		buttons->BTN_A = 0;
		buttons->BTN_B = 0;

		ScreenAnim_Start(old_state, ctx->state, ANIM_DIR_PREV); /* entre par la gauche */
	}
}

/* ===================================================================== */
/* HANDLERS DES ÉTATS (STATIQUES)                      */
/* ===================================================================== */

static void Handle_State_Speed(AppStateMachineContext *ctx,
		GNSS_StateHandle *gps, Buttons_t *buttons, AdcContext_t *gAdc,
		SDCard_struct *sd) {
	ssd1306_Fill(Black);
	if (gps->fgSpeed >= ctx->vitmax) {
		ctx->vitmax = gps->fgSpeed;
	}

	float pace = 0.0f;
	float sec = 0.0f;

	if (gps->fgSpeed != 0.0f) {
		pace = 1000.0f / (60.0f * gps->fgSpeed);
		sec = (pace - floorf(pace)) * 60.0f;
	} else {
		pace = 99.0f;
		sec = 59.0f;
	}

	float speed_kmh = gps->fgSpeed * 3.6f;
	float vitmax_kmh = ctx->vitmax * 3.6f;

	switch (ctx->spdstate) {
	case STATE_GROS:
		ssd1306_SetCursor(32, 32);
#ifndef USE_FAST_PRINT
		snprintf((char*) bufferscreen, 15, "%0.1f", speed_kmh);
#else
		fast_printf((char*) bufferscreen, NULL, speed_kmh, TYPE_FLOAT, 1,
				POS_PREFIX);
#endif
		ssd1306_WriteString((char*) bufferscreen, Font_16x24, White);

		ssd1306_SetCursor(32, 56);
		ssd1306_WriteString("Vit(kmh)", Font_6x8, White);

		batterygauge(gAdc->vbat, 79, 57, 1);

		if (buttons->BTN_B >= 1) {
			ctx->spdstate++;
			buttons->BTN_B = 0;
		}
		break;

	case STATE_GROS1:
		ssd1306_SetCursor(32, 32);
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

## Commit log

2024-08-27 add temperature sensor
2024-09-24 usb com device
2024-10-06 hardware v3
    [projet s6-B_Cu.gbr, projet s6-B_Mask.gbr, projet s6-B_Paste.gbr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]
2024-10-30 mode balise
    implementation du mode balise dans la memoire flash
    [projet s6-B_Cu.gbr, projet s6-B_Mask.gbr, projet s6-B_Paste.gbr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]
2024-11-02 step file
    [0.49 OLEd Assembly - No Glass.stp, 0.49 inch OLED 64x32 - Glass.stp, 0.49 inch OLED 64x32 - Without glass - Flat Mount.stp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]
2024-11-02 3d pcb v3
    [SM04B-SRSS-TB__LF__SN_.stp, projet s6.kicad_pcb]
2024-11-08 pcb v4 with ble
    [MLPF-WB-01E3.stp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]
2024-12-17 board v5 gps 25Hz !!
    [hardware v4 pro max.kicad_pcb, hardware v4 pro max.kicad_sch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]
2025-06-07 update code now on freertos with 10hz gps and 5hz balise
2025-06-12 hardware v7 esp32
    [MLPF-WB-01E3.stp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]
2026-07-03 Revise README with detailed project overview
    Expanded project details, features, and specifications for the Keyring-GPSTRACKER. Added modular hardware ecosystem and enclosure system descriptions.
2026-07-03 Update README with user attachments link
    Added a link to user attachments in the README.

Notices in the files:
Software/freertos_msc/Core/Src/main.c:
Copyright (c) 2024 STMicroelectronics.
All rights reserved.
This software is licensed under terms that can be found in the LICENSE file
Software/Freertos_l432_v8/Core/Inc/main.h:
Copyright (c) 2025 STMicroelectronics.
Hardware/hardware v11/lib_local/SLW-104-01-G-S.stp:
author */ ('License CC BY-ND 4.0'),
